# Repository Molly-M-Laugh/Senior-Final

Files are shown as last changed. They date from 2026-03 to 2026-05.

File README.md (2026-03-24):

## Welcome to Our Senior Design Project!

### Hardware

Put some base organization, hardware files in general should be put into the overall hardware folder unless:

- Microcontroller, should go into a designated section of software rather (TBD)
- Finalized circuits, hardware spec docs, and fabric designs (and others TBD) have specific hardware sub-folders

### Software

This folder includes our work on everything in our software stack. We have our code for our ESP32 handling BLE communication, IOS app code, our frontend website, and our backend api.

### Citations
We use a third party library that has been included into our repository because it was the only way to upload our work to the phone that we are developing on without deploying it. The library is called Alamofire, it's used for HTTP communication in Swift. You can find it at Software/BLE-IOS/Alamofire

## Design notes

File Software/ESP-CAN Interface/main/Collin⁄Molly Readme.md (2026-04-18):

# Cell_F103 ESP32

## Architecture

```
STM32 Sensor Node
      │
      │  CAN FD bus (hardware, done)
      │
   ESP32
      ├── can_ctrl.c     (done — do not modify)
      ├── mcp_port.c     (done — do not modify)
      ├── app_main.c     (Cannibalize into already done base)
      │
      └── ble_ctrl.c     ← Collin/Molly
      └── ble_ctrl.h     ← Collin/Molly
      │
      │  BLE 4.2
      │
   Mobile App
```

Data flows in two directions:

- **Telemetry (STM32 → App):** Hardware publishes sensor readings,
  power states, and alerts. `app_main.c` receives these and posts them
  to a queue. `ble_forward_task` drains the queue and calls
  `ble_ctrl_notify()` to push data to the connected mobile app.

- **Commands (App → STM32):** The mobile app writes to a BLE
  characteristic. The BLE write handler calls one of the pre-built
  `can_ctrl_send_cmd_*()` functions

---

## To-Do

### 1. `ble_ctrl_init()`

Called once at startup from `app_main.c`. Set up a GATT server with
the service and characteristics listed in the table below, then start
advertising so the mobile app can connect.

### 2. `ble_ctrl_notify(uint8_t char_id, const uint8_t *data, uint8_t len)`

Called from `ble_forward_task` in `app_main.c` when a telemetry frame
arrives. Send a BLE notification on the appropriate characteristic.
If no device is connected, discard silently (or buffer, your choice).

### 3. BLE write handler (commands from app → hardware)

When the mobile app writes to a command characteristic, call the
appropriate pre-built function from `can_ctrl.h`. See the command
table below for the exact function to call.

---

## GATT Service Layout

Use a custom 128-bit service UUID. Suggested base:
At Colins/Mollys discretion

### Telemetry Characteristics (notify, read)

These are written by the ESP32 and read/subscribed to by the mobile app.

| Characteristic | `char_id` constant | What it contains | Update rate |
|---|---|---|---|
| Sensor Data | `BLE_CHAR_SENSOR_DATA` | Temperatures (×3), current (×3), voltage (×3) | Periodic (~1 Hz) |
| Power State | `BLE_CHAR_POWER_STATE` | Which rails are on, fault flags | On change |
| Fault Alert | `BLE_CHAR_FAULT_ALERT` | Power rail fault condition | Event-driven |
| Temp Alert | `BLE_CHAR_TEMP_ALERT` | Which sensor, which limit, what reading | Event-driven |
| FRAM Log | `BLE_CHAR_FRAM_LOG` | Historical log chunk (48 bytes per chunk) | On request |

> **Note on alerts:** Use BLE **indications** (confirmed delivery) for
> `FAULT_ALERT` and `TEMP_ALERT` rather than unconfirmed notifications.
> These are safety-critical events.

### Command Characteristics (write, write-no-response)

These are written by the mobile app to control the hardware.

| Characteristic | `char_id` constant | Function to call | What it does |
|---|---|---|---|
| Power Control | `BLE_CHAR_CMD_POWER` | `can_ctrl_send_cmd_power(&pkt)` | Enable/disable a power rail |
| Temp Threshold | `BLE_CHAR_CMD_TEMP_THRESH` | `can_ctrl_send_cmd_temp_thresh(&pkt)` | Update a temperature alert limit |
| Temp Request | `BLE_CHAR_CMD_TEMP_REQ` | `can_ctrl_send_cmd_temp_req(&pkt)` | Request an immediate sensor reading |
| Alert Ack | `BLE_CHAR_CMD_ALERT_ACK` | `can_ctrl_send_cmd_alert_ack(&pkt)` | Acknowledge a temperature alert |

---

## Payload Structures

All payload structs are defined in `can_ctrl.h`. You do not need to
parse them on the ESP32 side, just forward the raw bytes to the mobile
app. The mobile app should parse them due to additional base overhead that would be added to the MCUs.

If you do need to inspect a field (e.g. for logging), the structs are:

```c
// Sensor data — arrives on BLE_CHAR_SENSOR_DATA
// Temperatures: divide temp_raw[n] by 16 to get °C as a float
typedef struct __attribute__((packed)) {
    can_frame_header_t hdr;       // 4 bytes — protocol header, ignore
    int16_t  temp_raw[3];         // TMP75B sensors 0/1/2
    int16_t  current_ma[3];       // INA3221 CH1/2/3 in mA
    uint16_t voltage_mv[3];       // INA3221 CH1/2/3 in mV
    uint32_t timestamp_ms;        // milliseconds since boot
} can_payload_sensor_data_t;      // 26 bytes total

// Power state — arrives on BLE_CHAR_POWER_STATE
typedef struct __attribute__((packed)) {
    can_frame_header_t hdr;
    uint8_t  rails_enabled;       // bit0=5V, bit1=3V3, bit2=1V8
    uint8_t  rails_pg;            // bit0=5V power-good, bit1=3V3 power-good
    uint8_t  fault_flags;         // non-zero means a rail has faulted
    uint8_t  reserved;
    uint32_t timestamp_ms;
} can_payload_power_state_t;      // 12 bytes

// Fault alert — arrives on BLE_CHAR_FAULT_ALERT
typedef struct __attribute__((packed)) {
    can_frame_header_t hdr;
    uint8_t  fault_flags;         // which rails faulted (same bit layout as above)
    uint8_t  reserved[3];
    uint32_t timestamp_ms;
} can_payload_fault_alert_t;      // 12 bytes

// Temperature alert — arrives on BLE_CHAR_TEMP_ALERT
typedef struct __attribute__((packed)) {
    can_frame_header_t hdr;
    uint8_t  sensor_idx;          // which sensor (0, 1, or 2)
    uint8_t  alert_type;          // 0 = high limit breached, 1 = low limit
    int16_t  temp_raw;            // current reading (divide by 16 for °C)
    int16_t  threshold_raw;       // the limit that was breached
    uint8_t  reserved[2];
    uint32_t timestamp_ms;
} can_payload_temp_alert_t;       // 16 bytes
```

### Building a command packet

When the app sends a command, you build a packet and call the
appropriate function. Example if the app requests an immediate reading:

```c
#include "can_ctrl.h"

void on_ble_temp_req_write(const uint8_t *data, uint16_t len)
{
    can_payload_cmd_temp_req_t pkt = {0};
    // hdr is filled automatically inside can_ctrl_send_cmd_temp_req()
    pkt.sensor_mask = 0x07;   // request all three sensors (bits 0,1,2)
    can_ctrl_send_cmd_temp_req(&pkt);
}
```

Example if app wants to update a temperature threshold:

```c
void on_ble_temp_thresh_write(const uint8_t *data, uint16_t len)
{
    can_payload_cmd_temp_thresh_t pkt = {0};
    pkt.sensor_idx    = data[0];          // 0, 1, or 2
    pkt.limit_type    = data[1];          // 0 = T_HIGH, 1 = T_LOW
    pkt.threshold_raw = (int16_t)(data[2] << 4); // °C × 16, e.g. 45°C = 720
    can_ctrl_send_cmd_temp_thresh(&pkt);
}
```

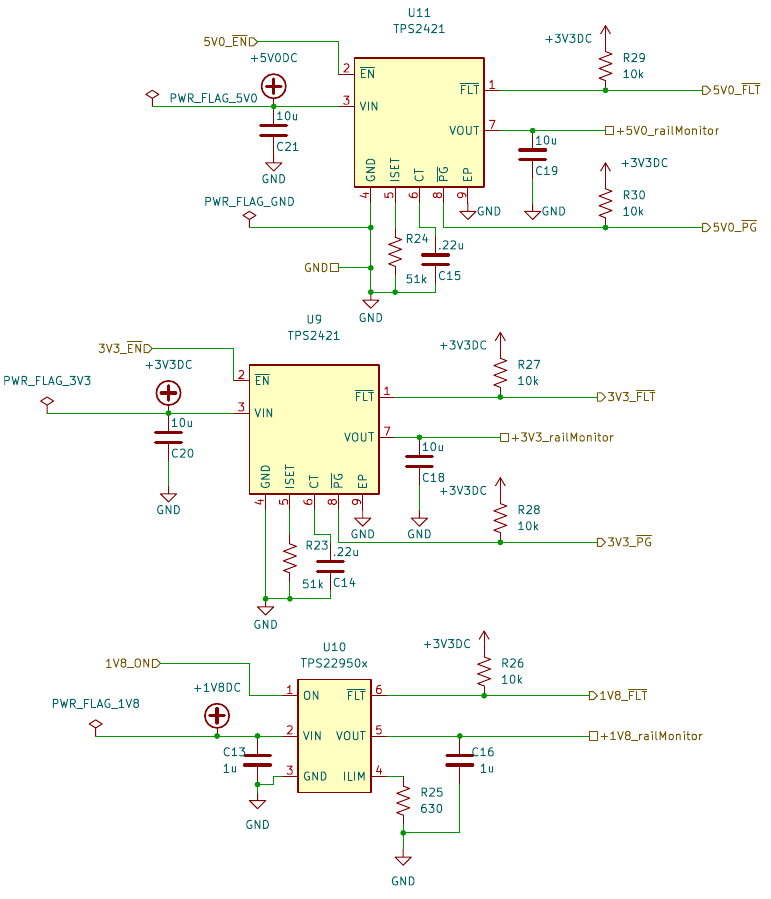
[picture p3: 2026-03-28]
Schematic page 4.png

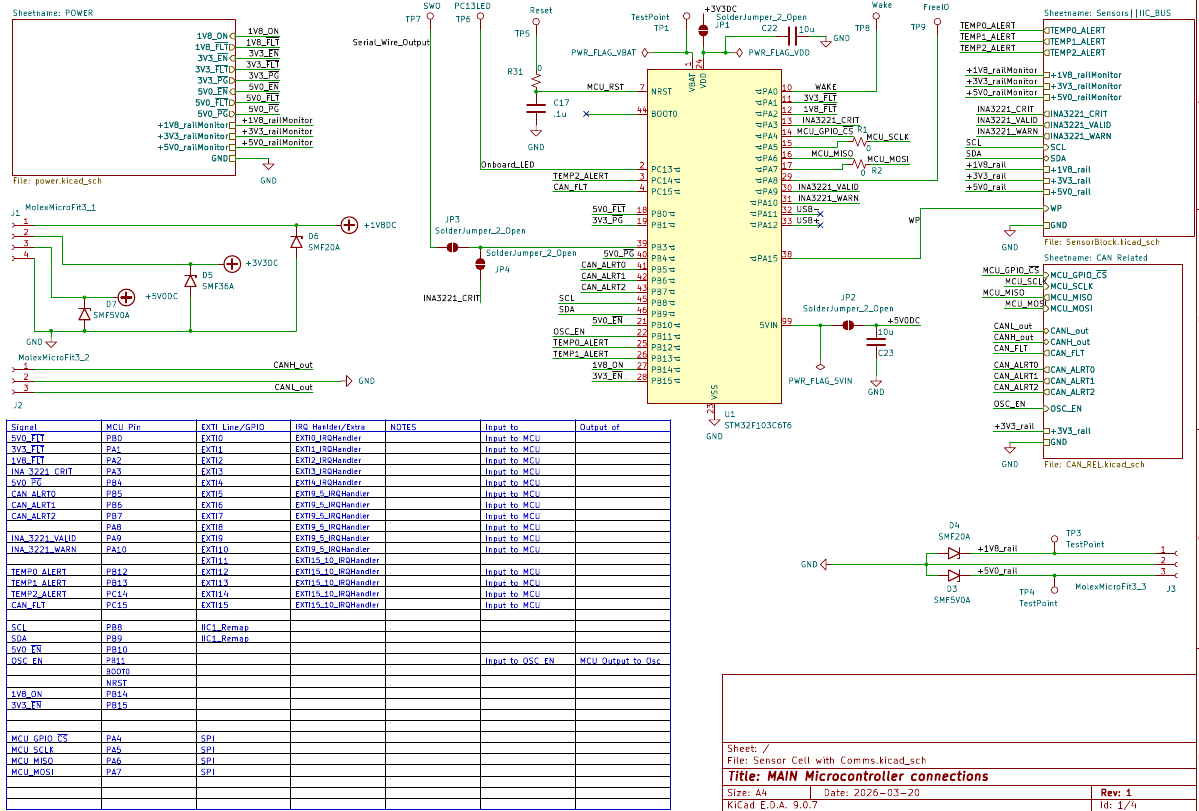
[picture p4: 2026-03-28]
Schematic page 1.png

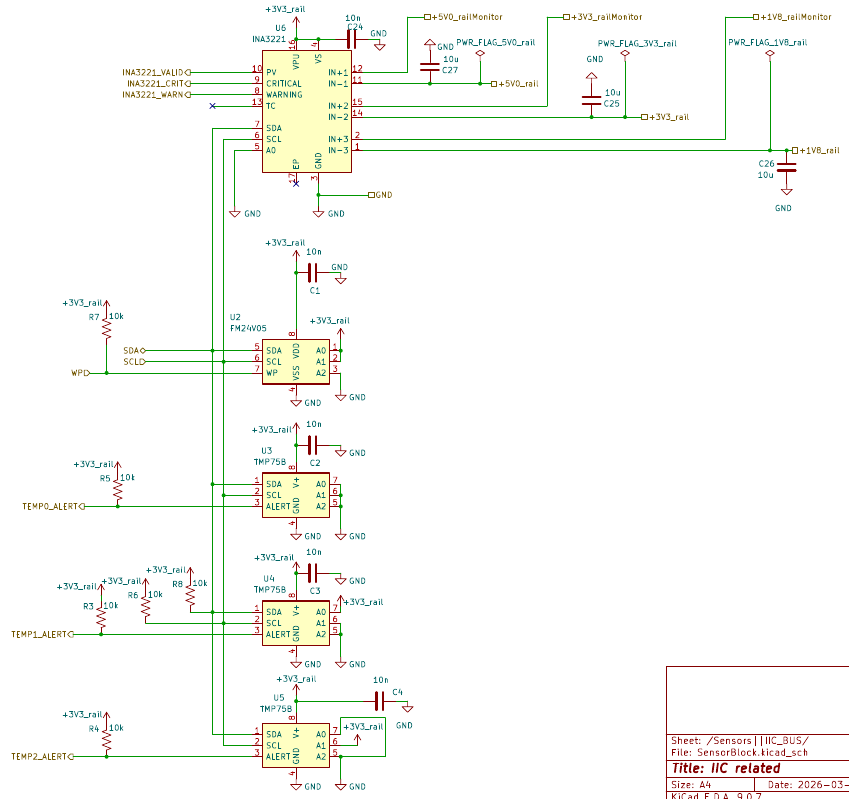
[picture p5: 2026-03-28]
Schematic page 2.png

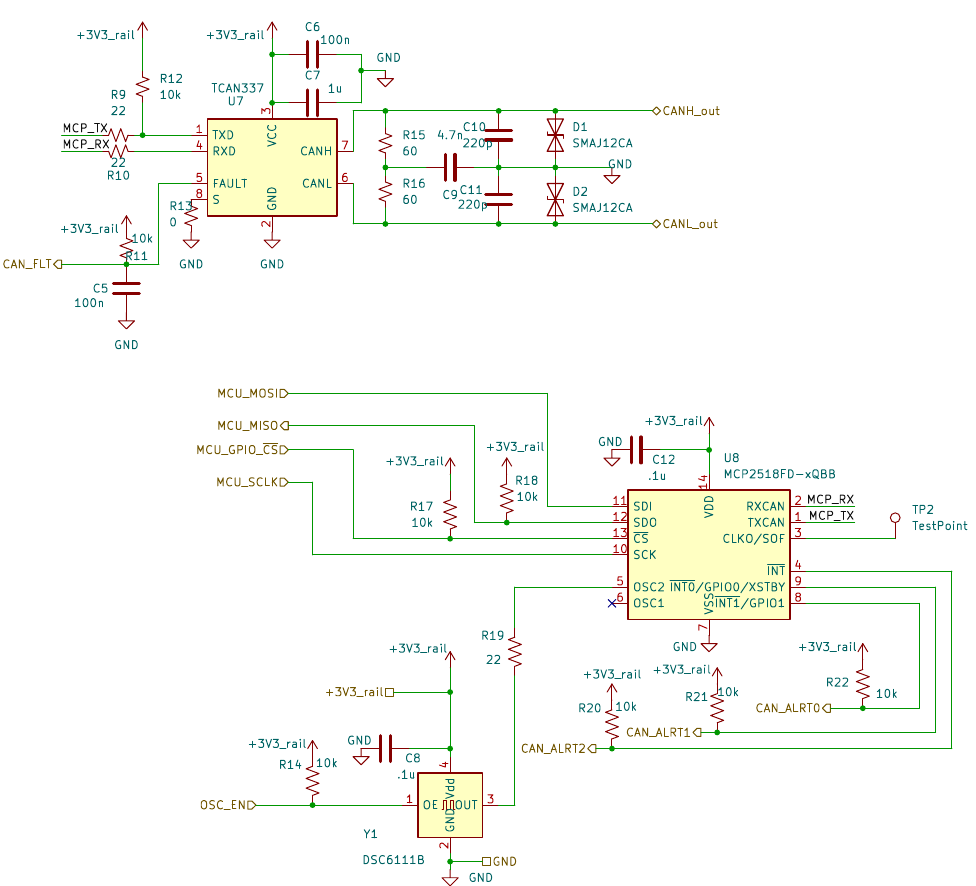
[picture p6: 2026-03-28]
Schematic page 3.png

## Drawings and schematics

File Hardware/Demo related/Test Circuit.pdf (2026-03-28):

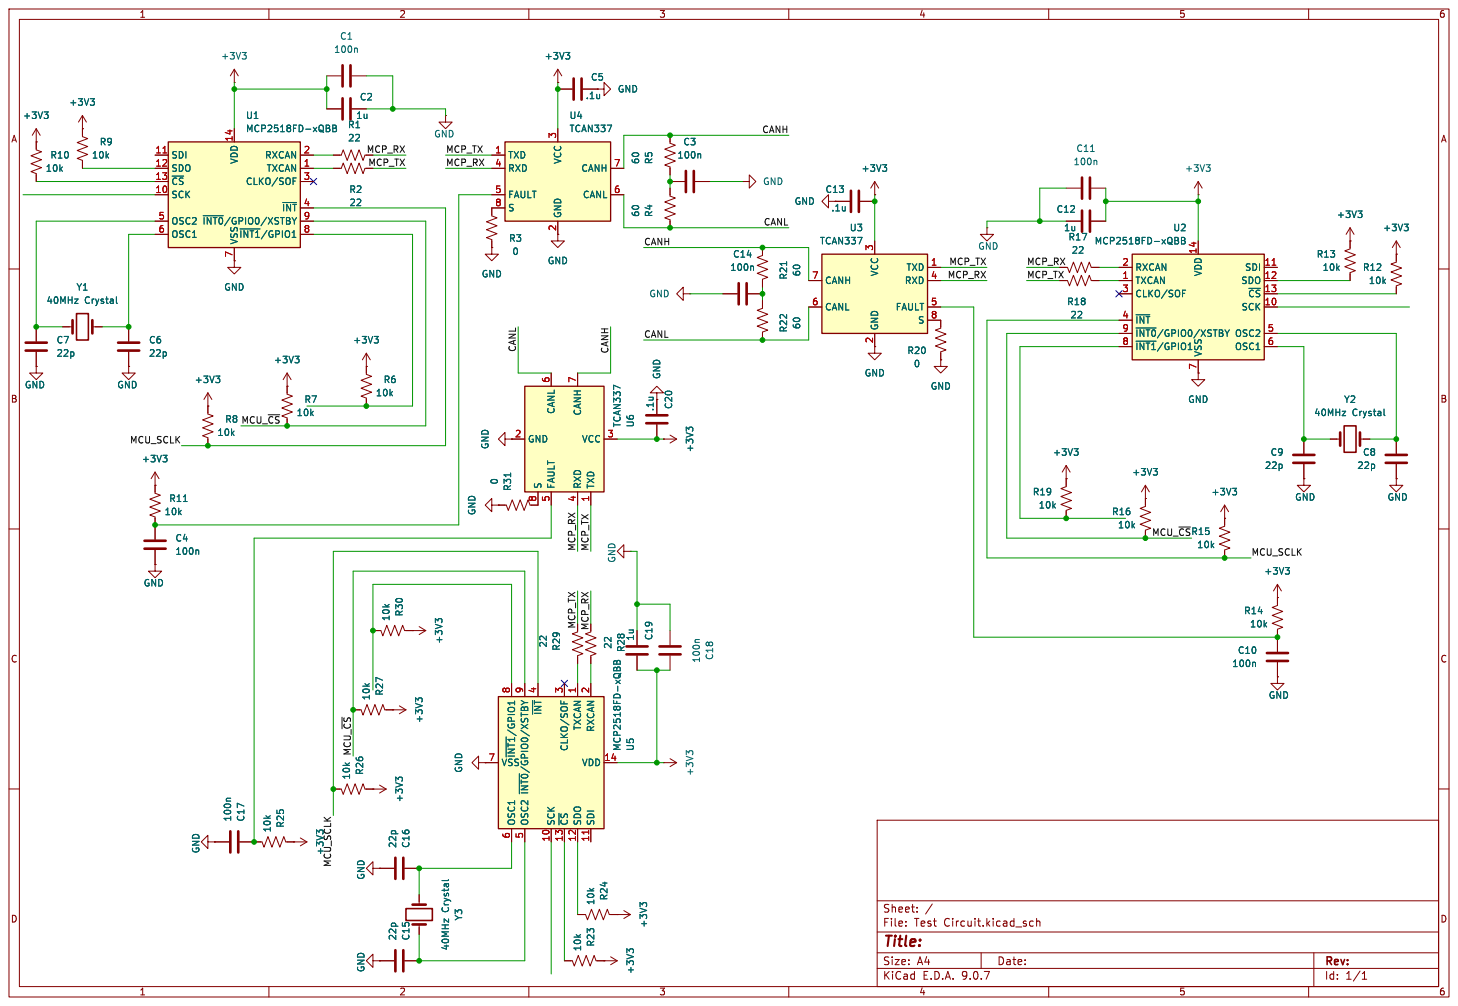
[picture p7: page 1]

7 RXCAN 2 TXCAN 1 CLKO/SOF 3 ~{INT}4 ~{INT0}/GPIO0/XSTBY 9 ~{INT1}/GPIO1 8 U1 MCP2518FD-xQBB GND

7 RXCAN 2 TXCAN 1 CLKO/SOF 3 ~{INT}4 ~{INT0}/GPIO0/XSTBY 9 ~{INT1}/GPIO1 8 GND

2 CANH 7 CANL 6 U3 TCAN337 GND GND

7 RXCAN 2 TXCAN 1 CLKO/SOF 3 ~{INT} 4 ~{INT0}/GPIO0/XSTBY 9 ~{INT1}/GPIO1 8 U2 MCP2518FD-xQBB GND

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

Id: 1/1 Title: File: Test Circuit.kicad_sch Sheet: /

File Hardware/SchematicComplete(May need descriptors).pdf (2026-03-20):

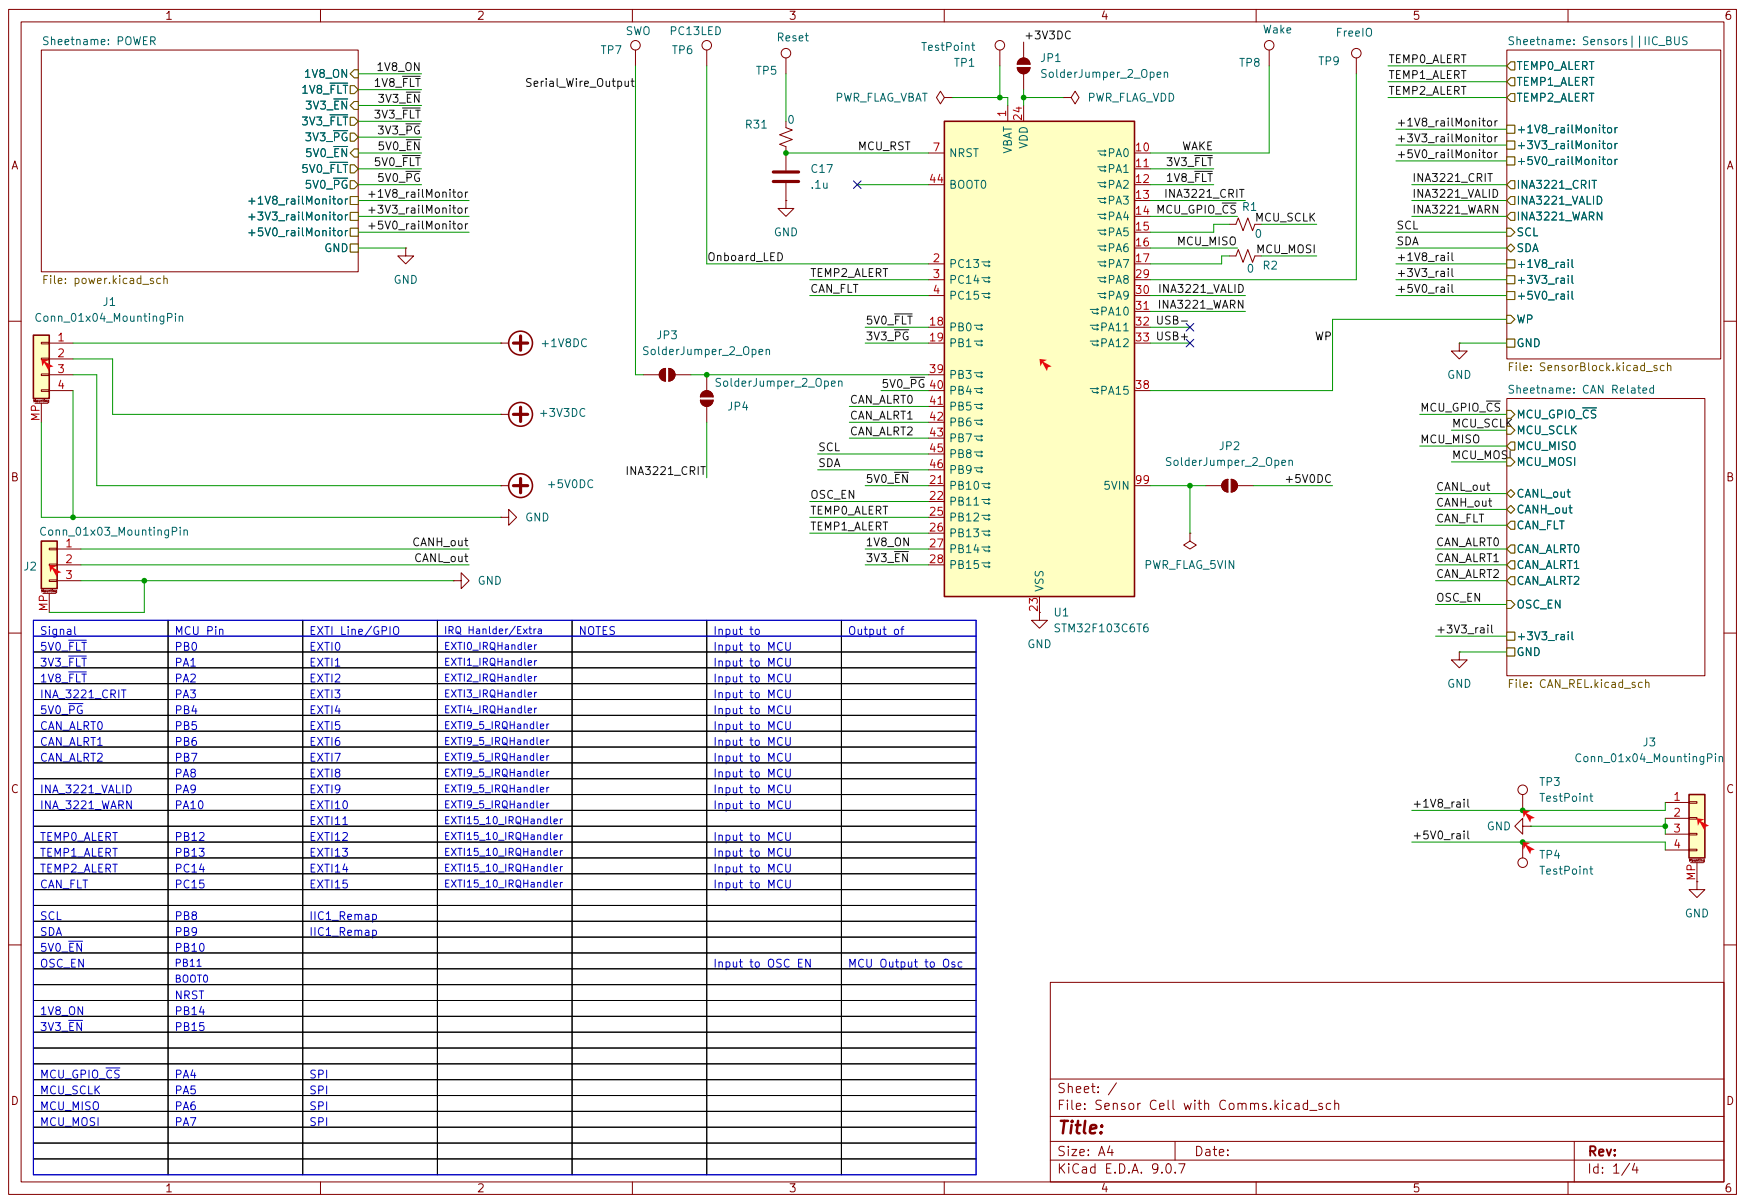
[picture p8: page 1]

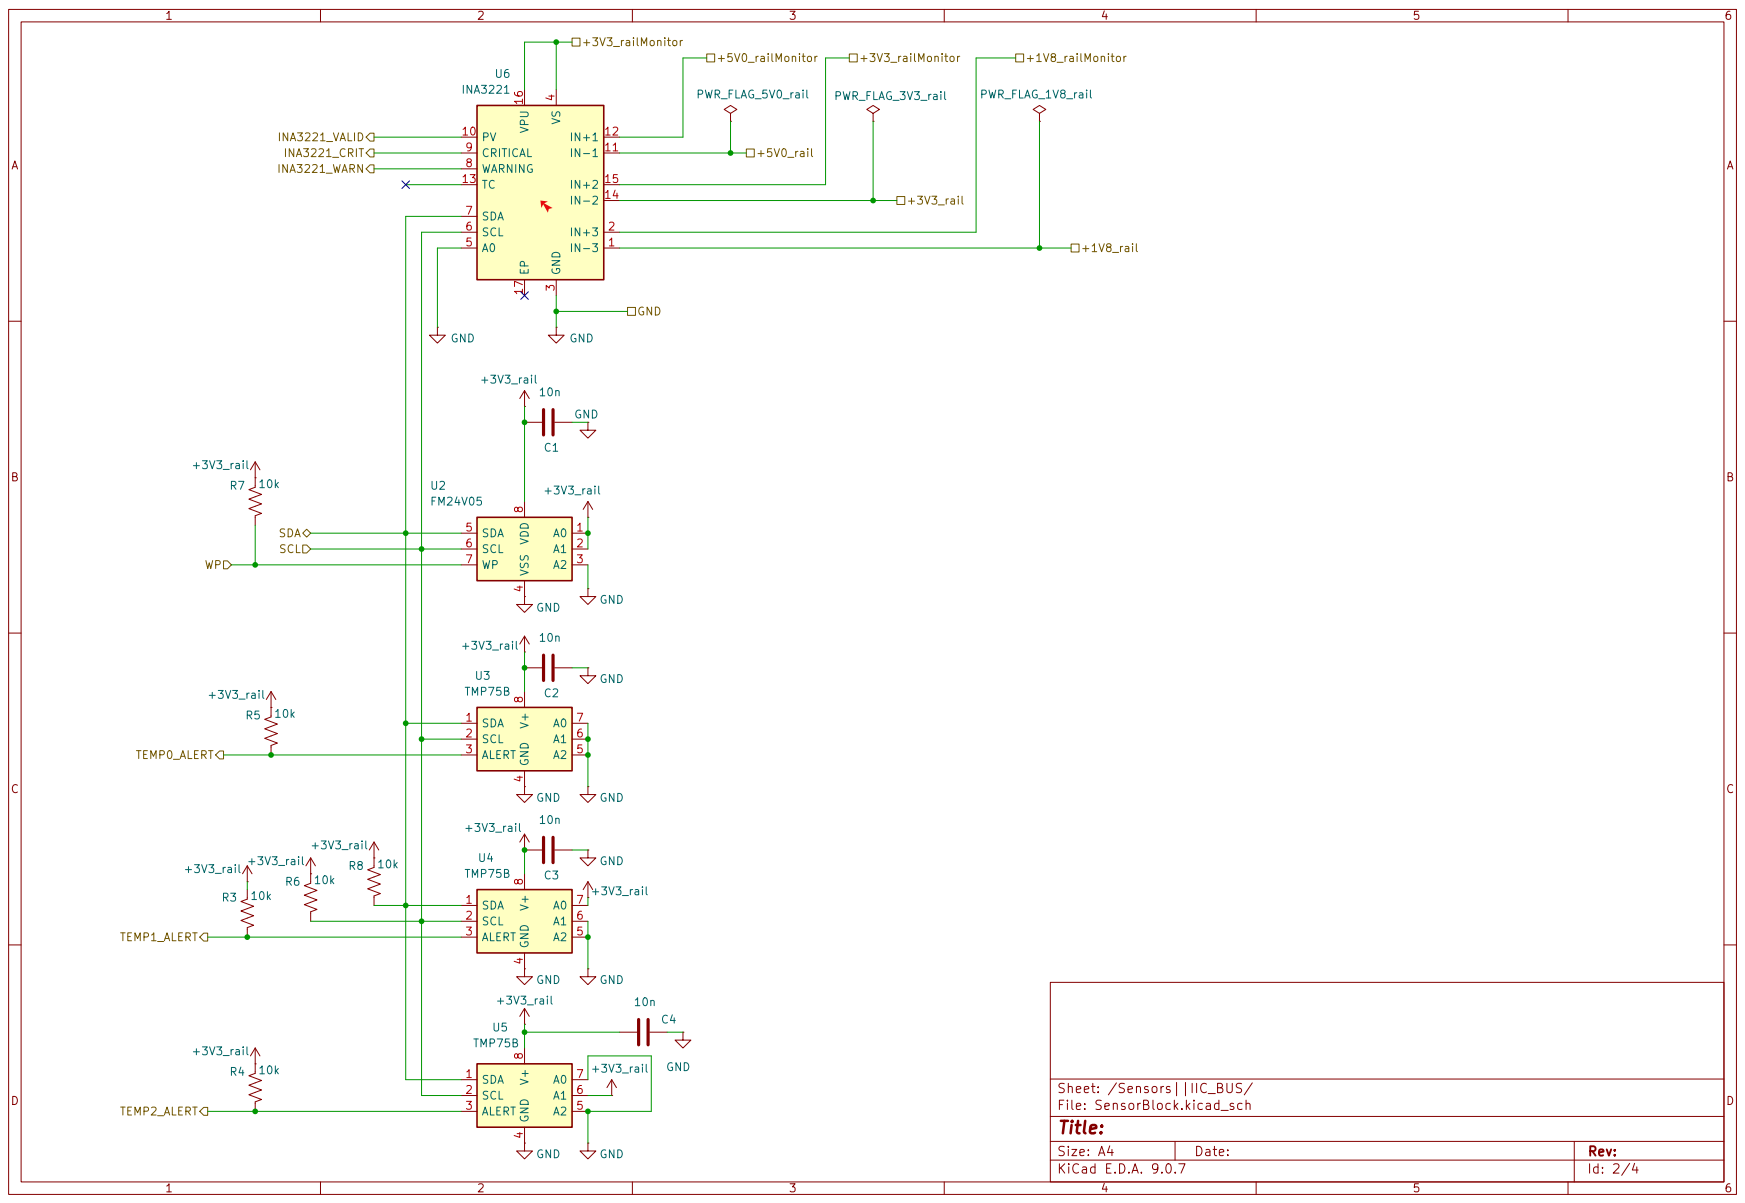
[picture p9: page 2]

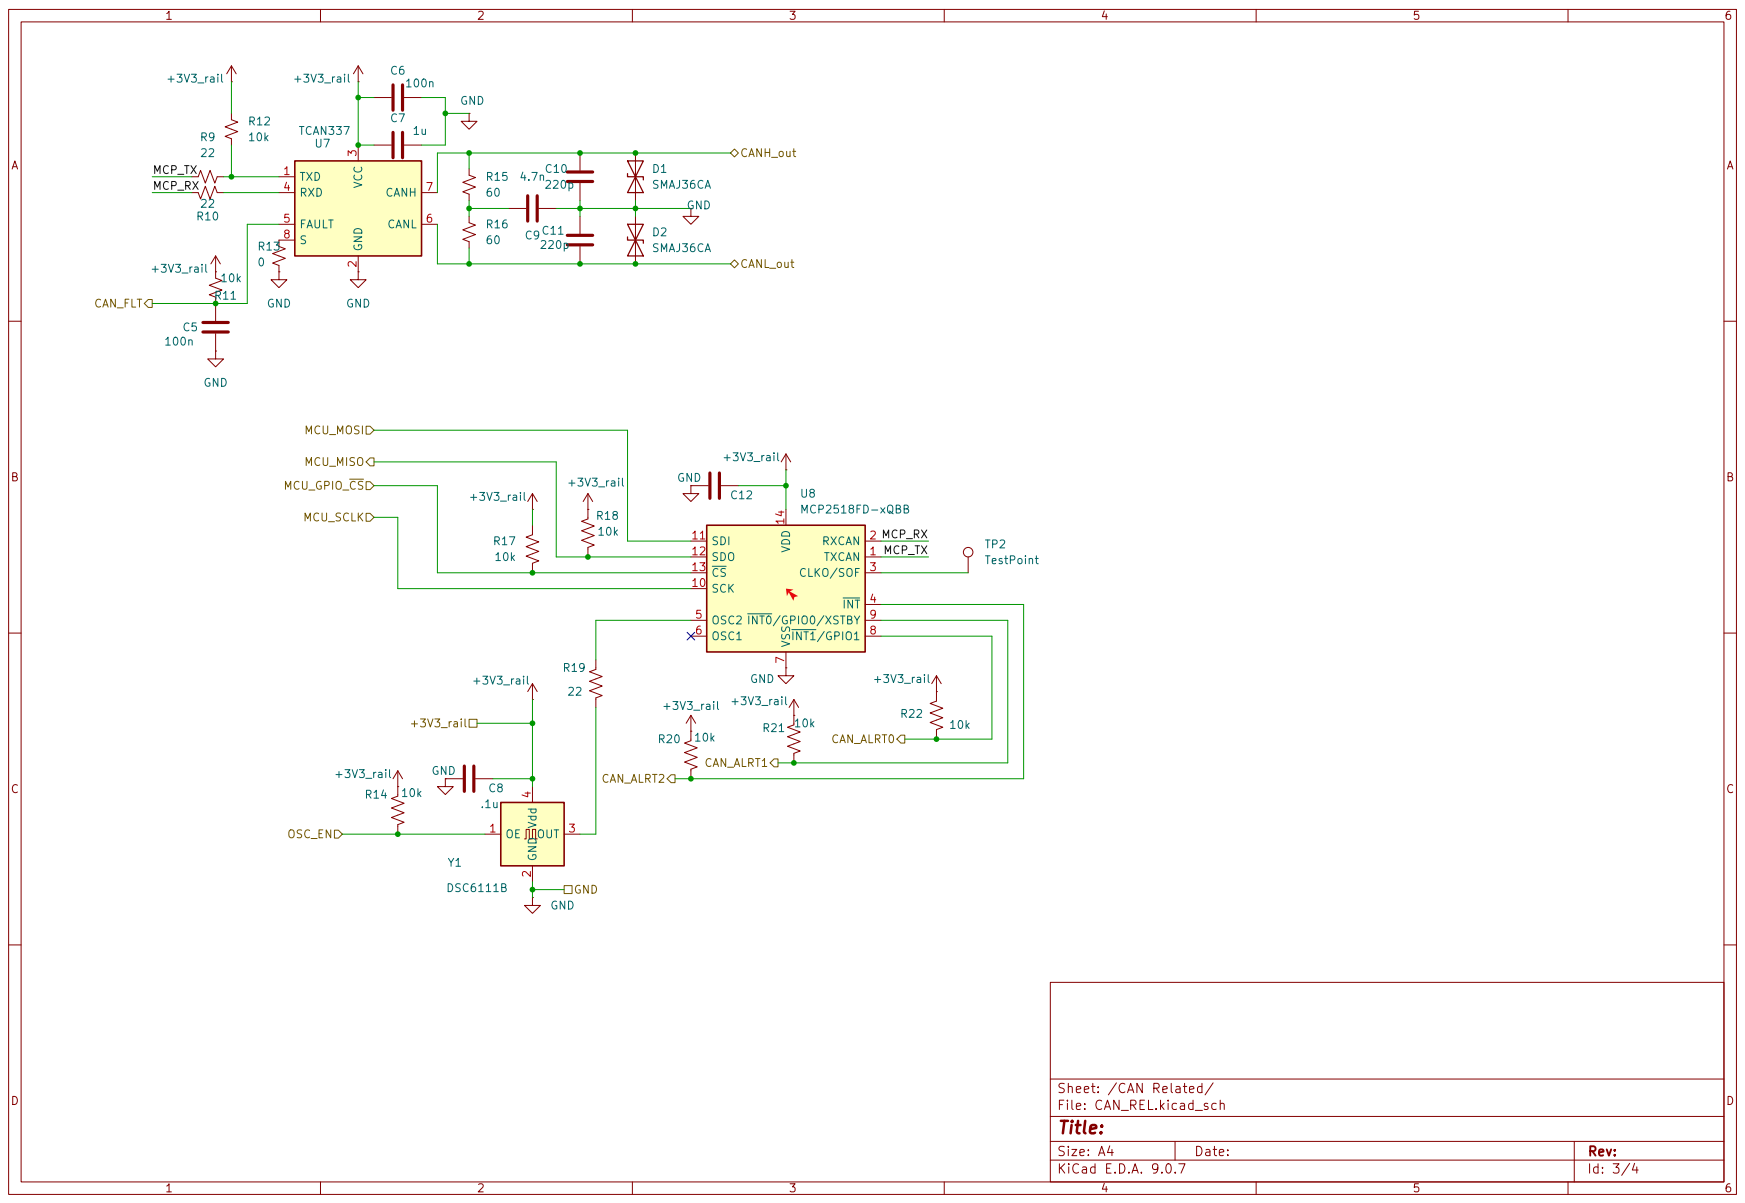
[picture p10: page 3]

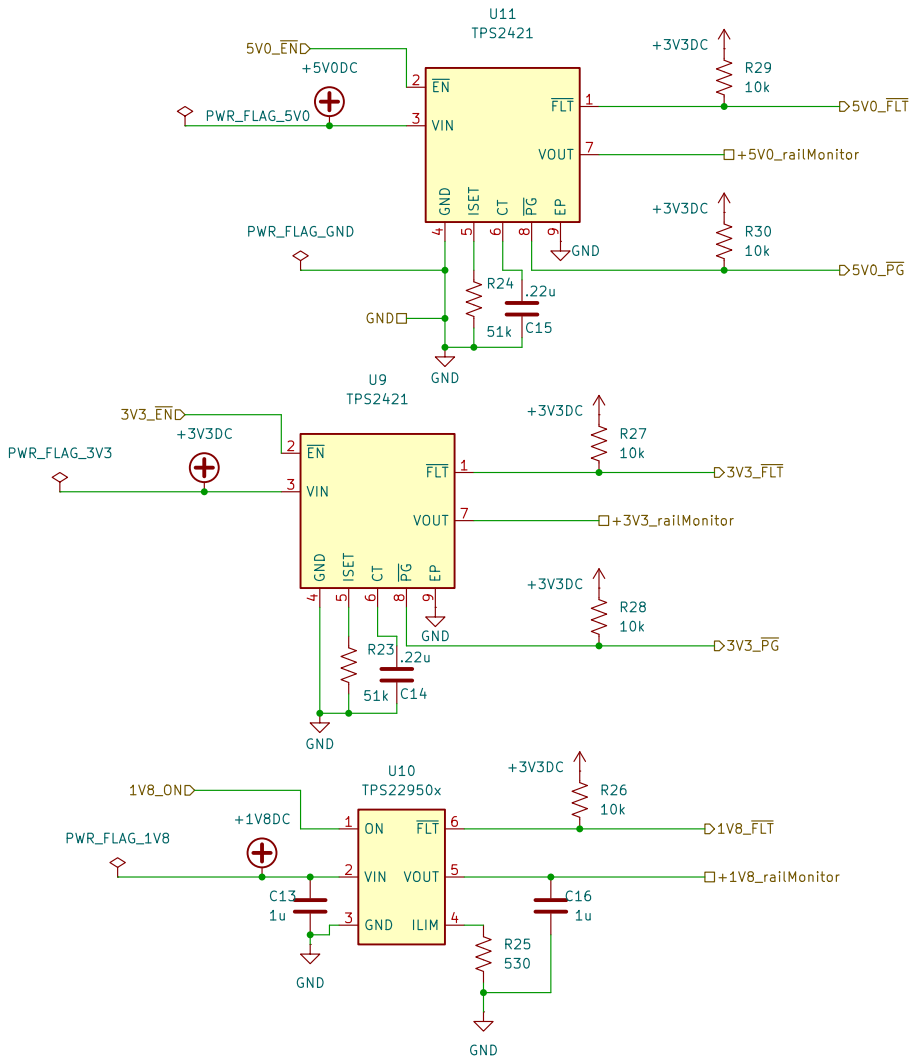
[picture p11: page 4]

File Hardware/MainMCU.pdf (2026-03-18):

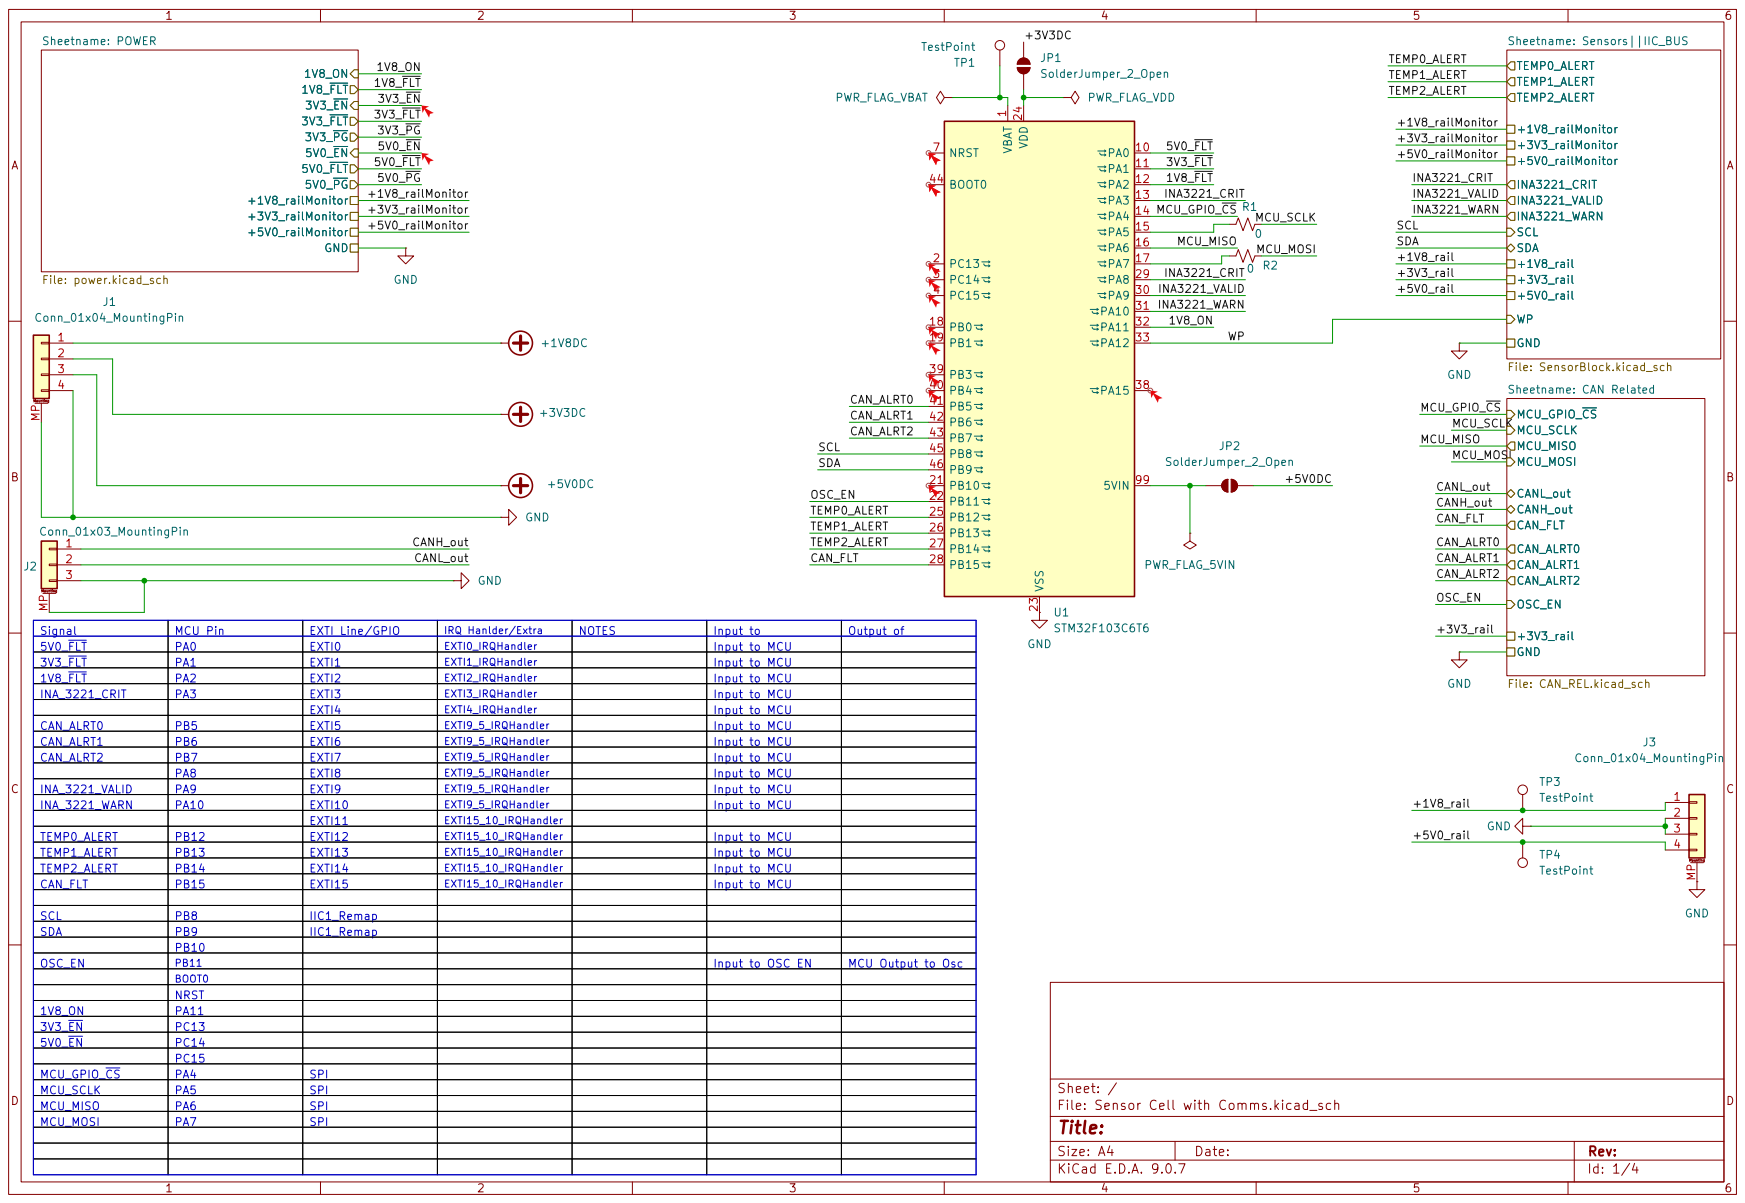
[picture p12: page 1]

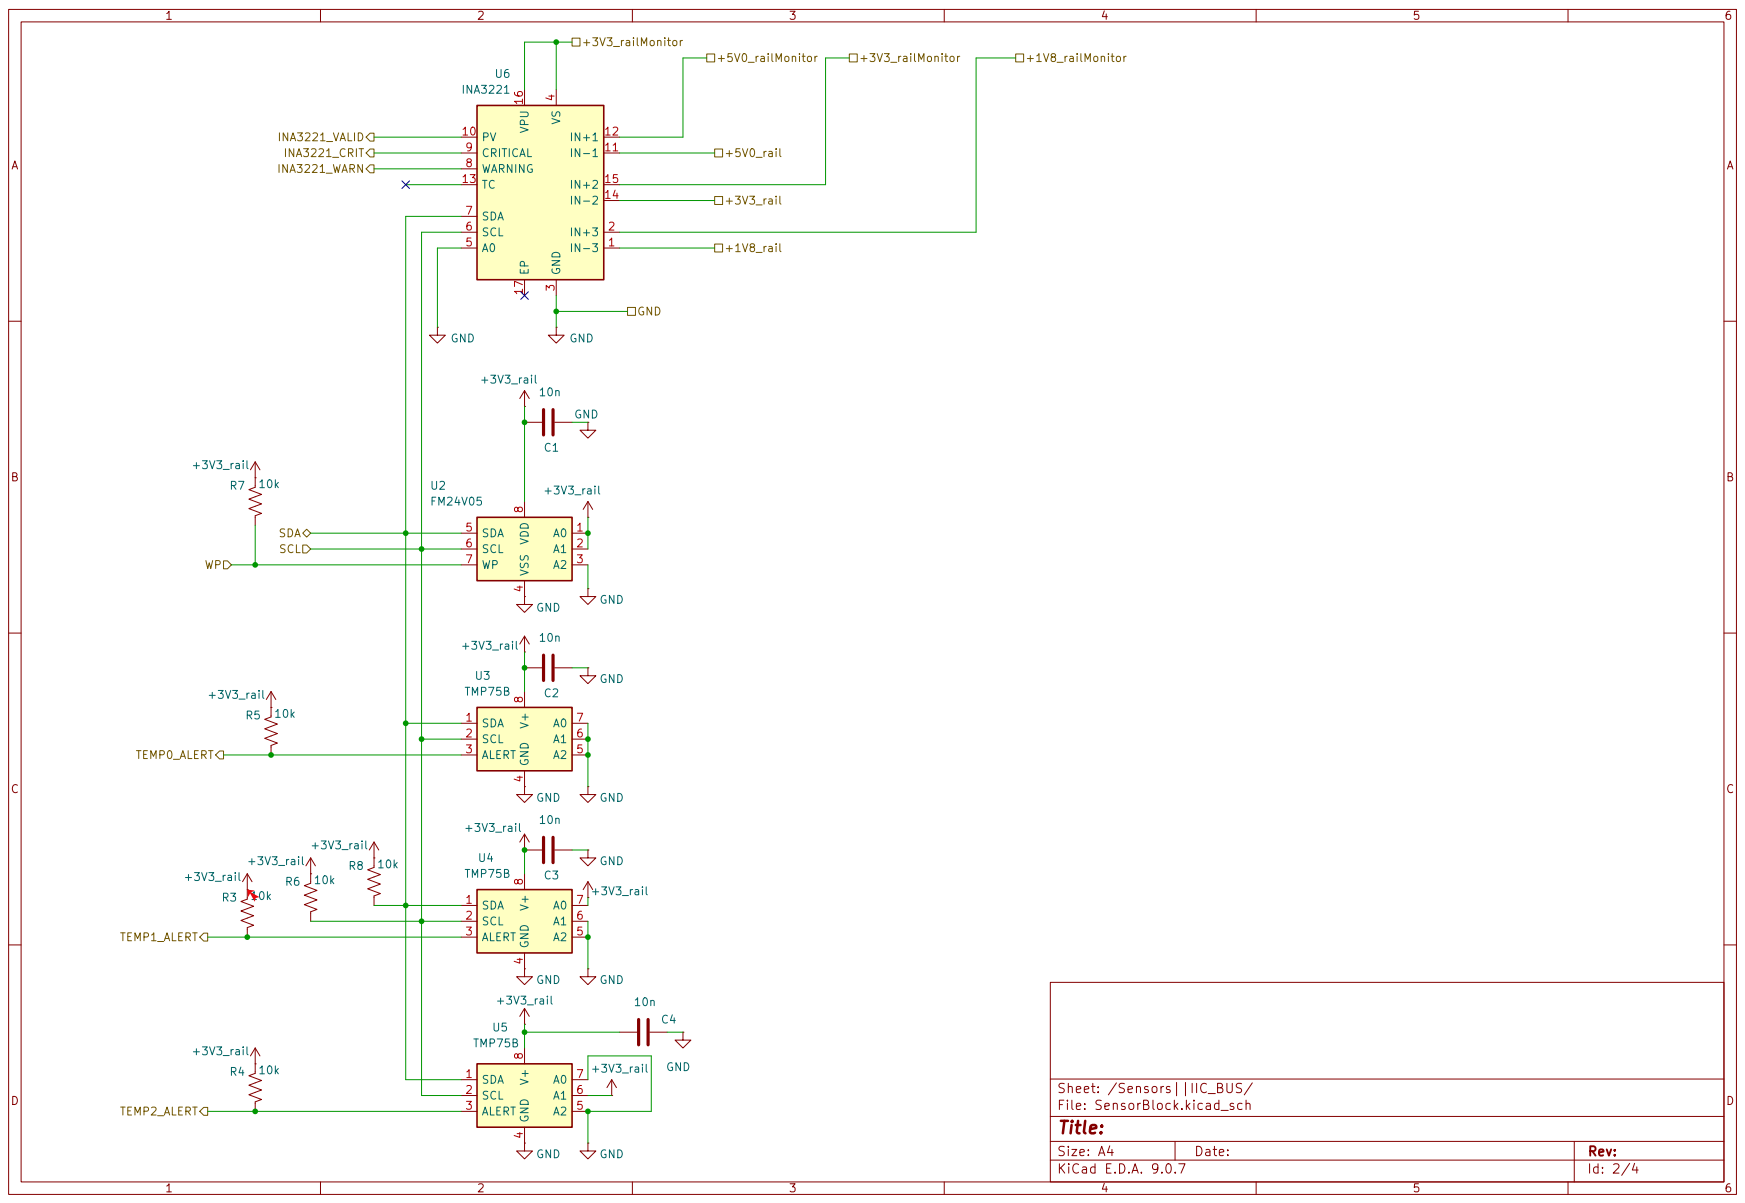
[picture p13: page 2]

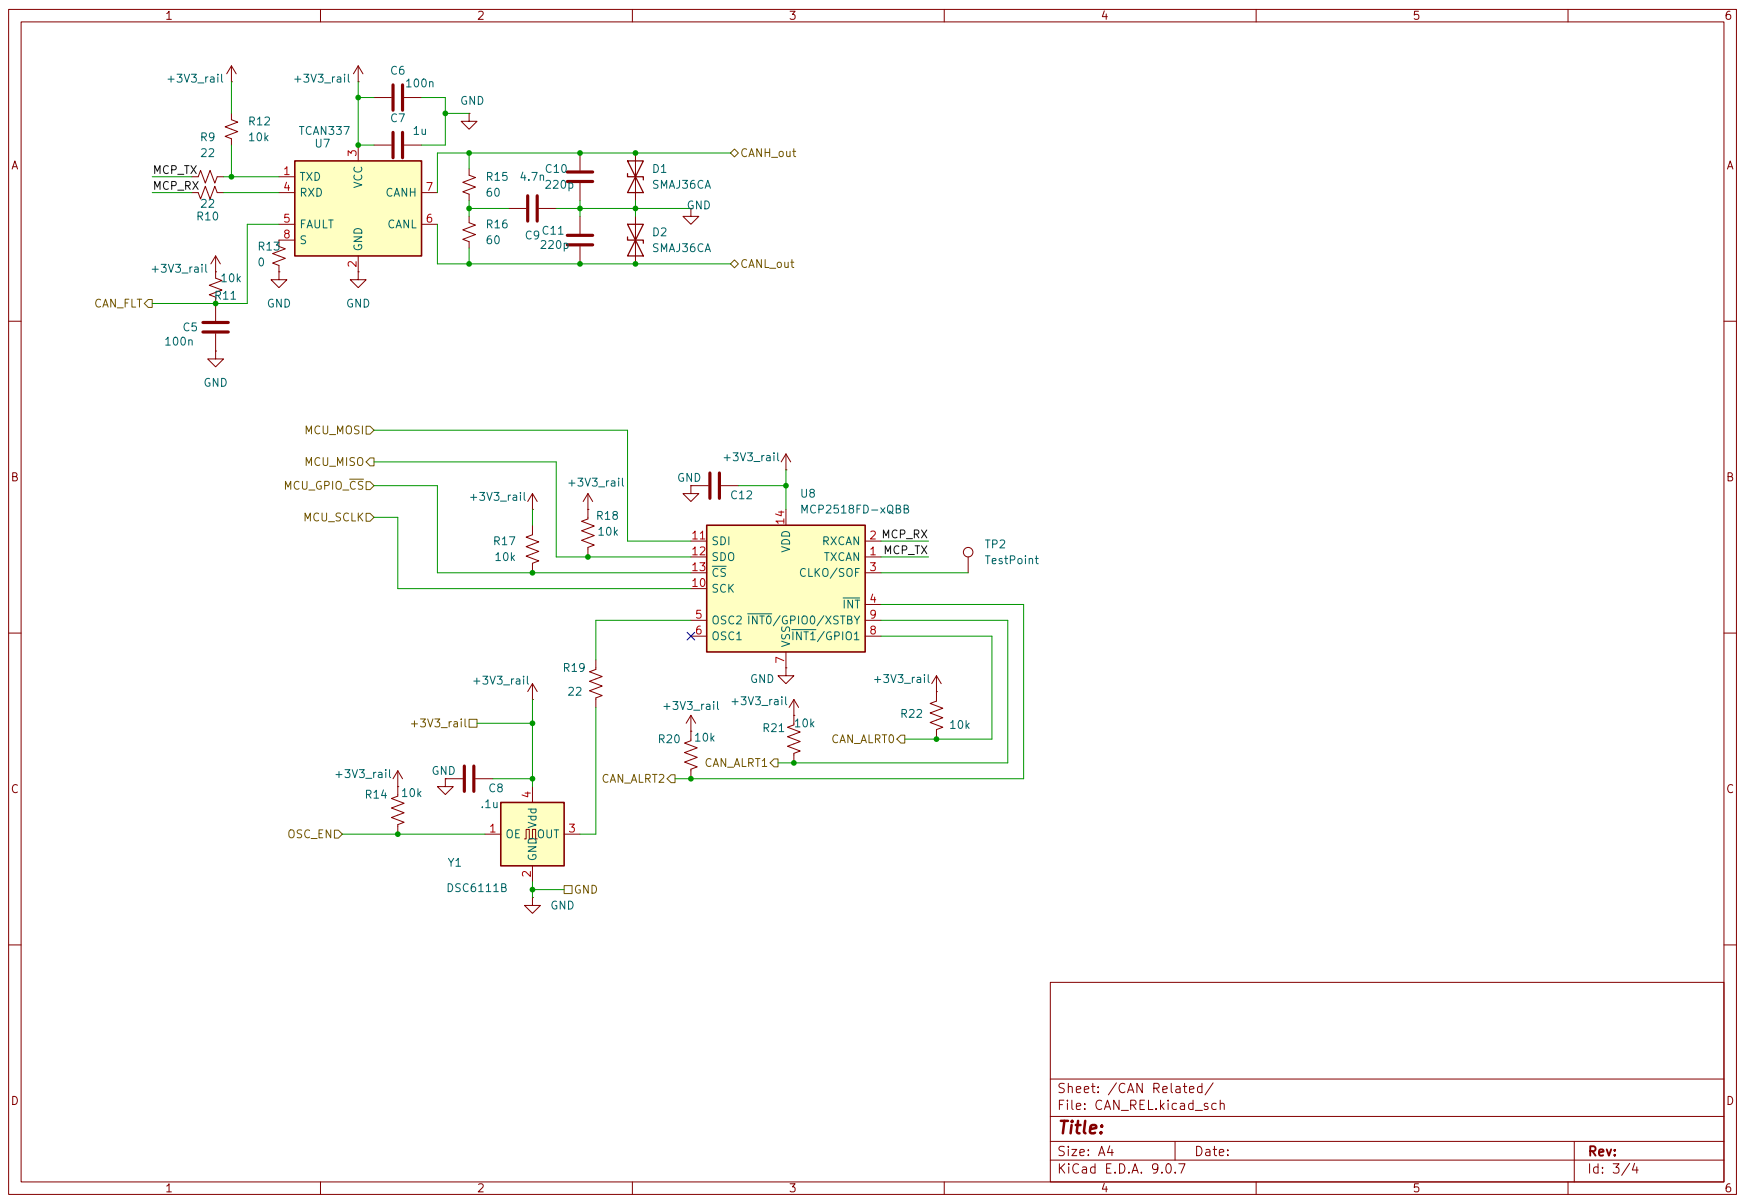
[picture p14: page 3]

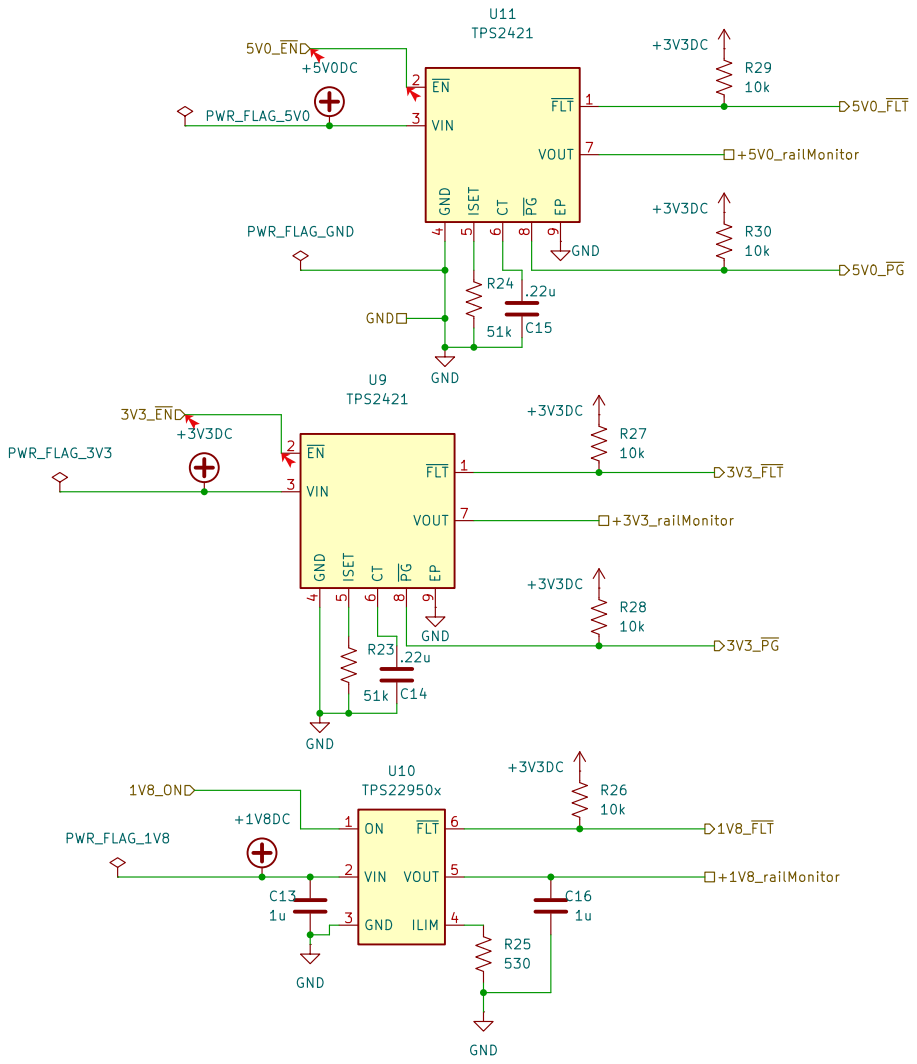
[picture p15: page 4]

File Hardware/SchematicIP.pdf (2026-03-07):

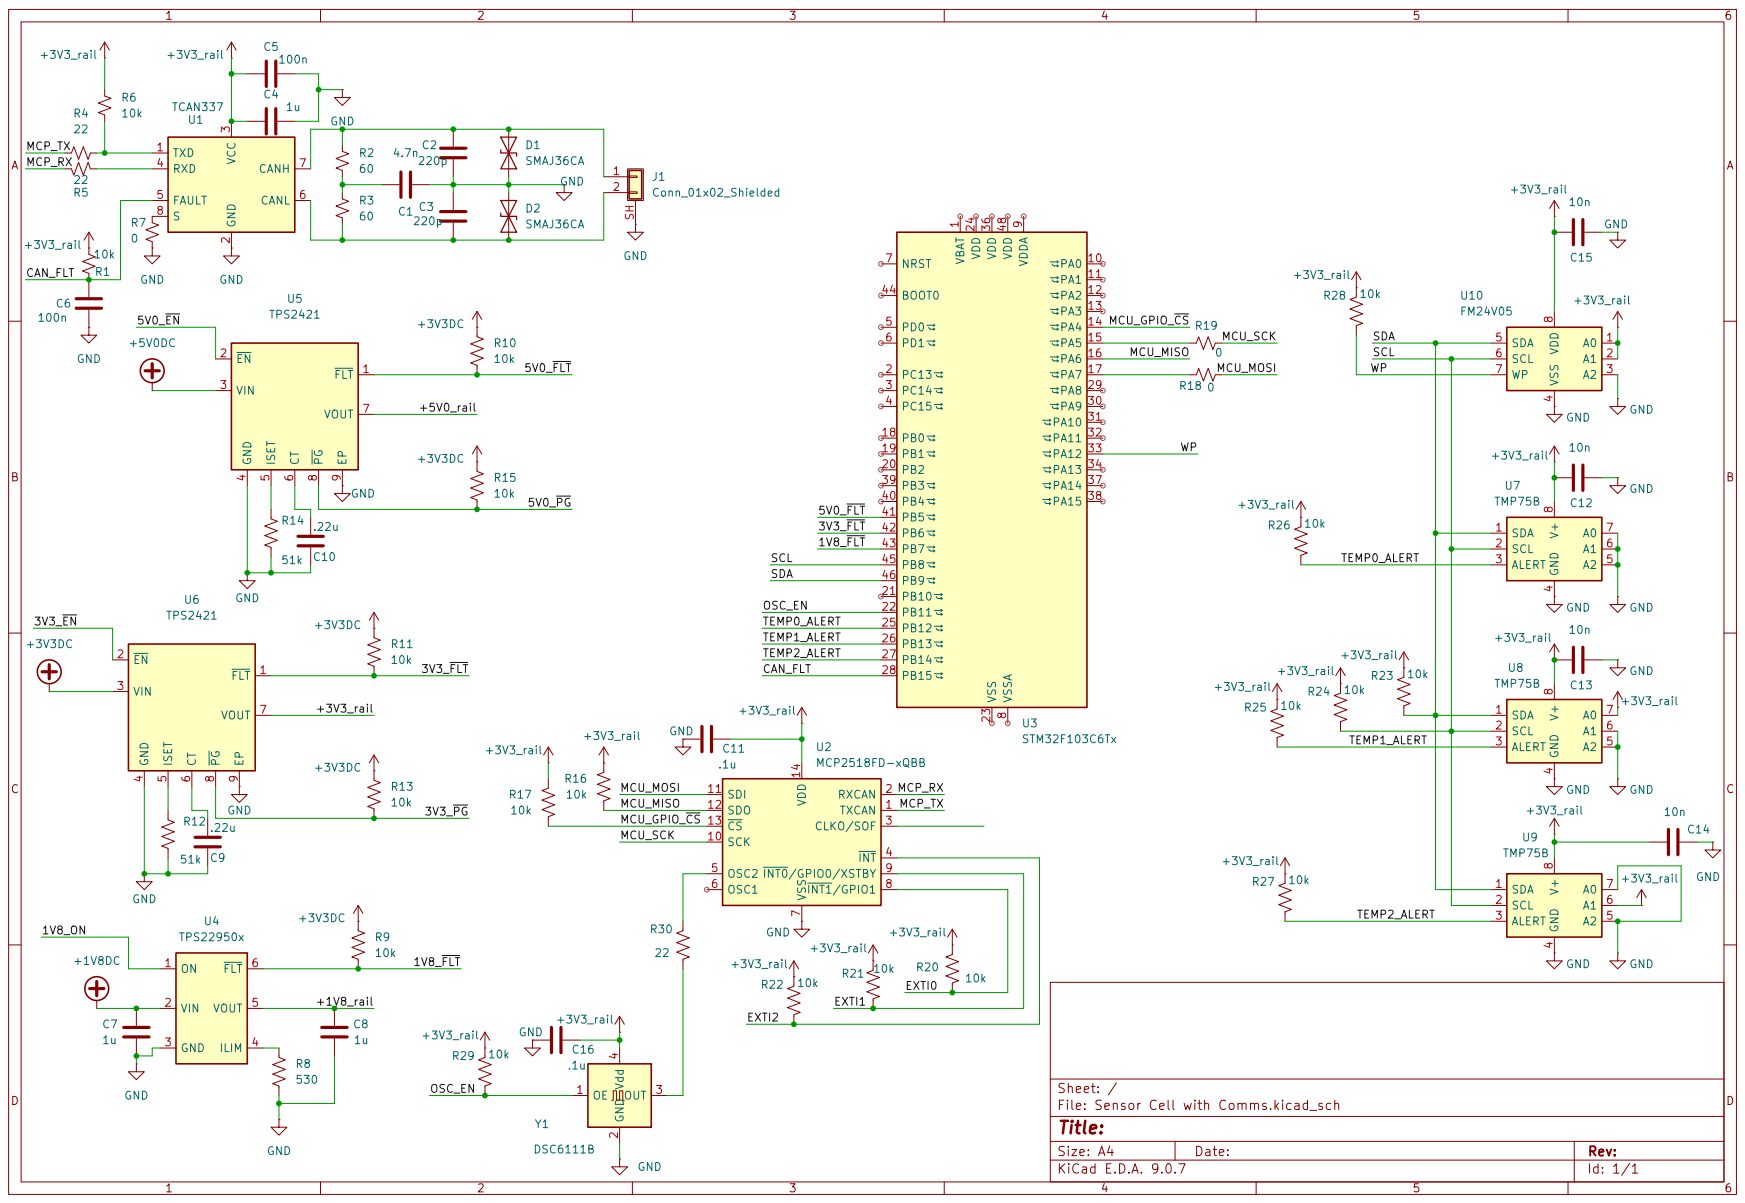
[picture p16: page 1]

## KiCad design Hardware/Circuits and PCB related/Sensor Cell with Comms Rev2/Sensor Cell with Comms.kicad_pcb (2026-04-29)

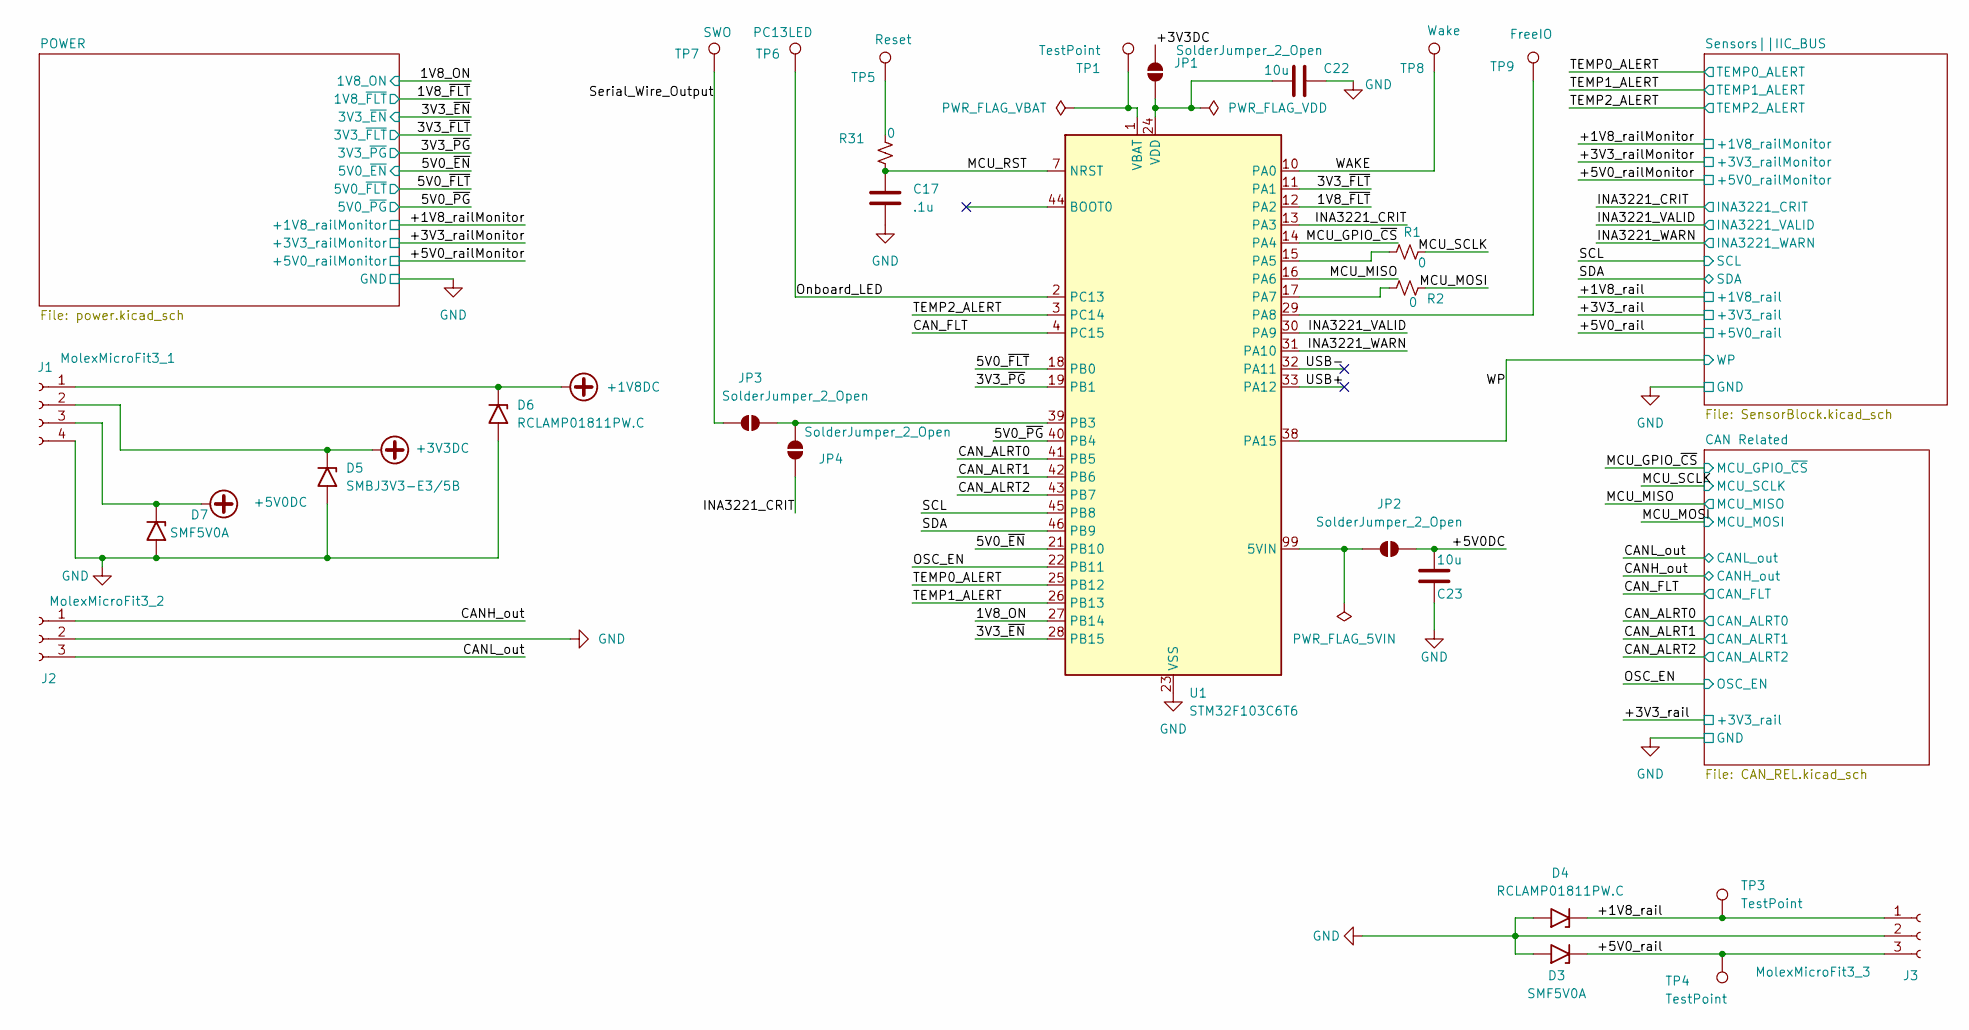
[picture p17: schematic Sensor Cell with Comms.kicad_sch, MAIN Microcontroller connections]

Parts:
C17: .1u; C_0805_2012Metric_Pad1.18x1.45mm_HandSolder
C22, C23: 10u; C_0603_1608Metric_Pad1.08x0.95mm_HandSolder
D3, D7: SMF5V0A; D_SMF
D4, D6: RCLAMP01811PW.C; D_SMF
D5: SMBJ3V3-E3/5B; D_SMF
J1: MolexMicroFit3_1; Molex_Micro-Fit_3.0_43650-0400_1x04_P3.00mm_Horizontal
J2: MolexMicroFit3_2; CONN_SD-43650-001_03_MOL
J3: MolexMicroFit3_3; CONN_SD-43650-001_03_MOL
JP1, JP2, JP3, JP4: SolderJumper_2_Open; SolderJumper-2_P1.3mm_Open_TrianglePad1.0x1.5mm
R1, R2, R31: 0; R_0603_1608Metric_Pad0.98x0.95mm_HandSolder
TP1, TP3, TP4: TestPoint; PinHeader_1x01_P1.00mm_Vertical
TP5: Reset; PinHeader_1x01_P1.00mm_Vertical
TP6: PC13LED; PinHeader_1x01_P1.00mm_Vertical
TP7: SWO; PinHeader_1x01_P1.00mm_Vertical
TP8: Wake; PinHeader_1x01_P1.00mm_Vertical
TP9: FreeIO; PinHeader_1x01_P1.00mm_Vertical
U1: STM32F103C6T6; PinHeader_1x20_P1.00mm_Verticalx2

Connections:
+1V8DC: D6.1 (A1), J1.1; also elsewhere on the board
+3V3DC: D5.1 (A1), J1.2, JP1.2 (B); also elsewhere on the board
+5V0DC: C23.2, D7.1 (A1), J1.3, JP2.2 (B); also elsewhere on the board
/1V8_ON: U1.27 (PB14); also elsewhere on the board
/1V8_~FLT: U1.12 (PA2); also elsewhere on the board
/3V3_~EN: U1.28 (PB15); also elsewhere on the board
/3V3_~FLT: U1.11 (PA1); also elsewhere on the board
/3V3_~PG: U1.19 (PB1); also elsewhere on the board
/5V0_~EN: U1.21 (PB10); also elsewhere on the board
/5V0_~FLT: U1.18 (PB0); also elsewhere on the board
/5V0_~PG: U1.40 (PB4); also elsewhere on the board
/+1V8_rail: D4.1 (A1), J3.1, TP3.1; also elsewhere on the board
/+5V0_rail: D3.1 (A1), J3.3, TP4.1; also elsewhere on the board
/CANH_out: J2.1; also elsewhere on the board
/CANL_out: J2.3; also elsewhere on the board
/CAN_ALRT0: U1.41 (PB5); also elsewhere on the board
/CAN_ALRT1: U1.42 (PB6); also elsewhere on the board
/CAN_ALRT2: U1.43 (PB7); also elsewhere on the board
/CAN_FLT: U1.4 (PC15); also elsewhere on the board
/INA3221_CRIT: JP4.2 (B), U1.13 (PA3); also elsewhere on the board
/INA3221_VALID: U1.30 (PA9); also elsewhere on the board
/INA3221_WARN: U1.31 (PA10); also elsewhere on the board
/MCU_GPIO_~CS: U1.14 (PA4); also elsewhere on the board
/MCU_MISO: U1.16 (PA6); also elsewhere on the board
/MCU_MOSI: R2.1; also elsewhere on the board
/MCU_RST: C17.1, R31.2, U1.7 (NRST)
/MCU_SCLK: R1.1; also elsewhere on the board
/OSC_EN: U1.22 (PB11); also elsewhere on the board
/Onboard_LED: TP6.1, U1.2 (PC13)
/SCL: U1.45 (PB8); also elsewhere on the board
/SDA: U1.46 (PB9); also elsewhere on the board
/Serial_Wire_Output: JP3.1 (A), TP7.1
/TEMP0_ALERT: U1.25 (PB12); also elsewhere on the board
/TEMP1_ALERT: U1.26 (PB13); also elsewhere on the board
/TEMP2_ALERT: U1.3 (PC14); also elsewhere on the board
/USB+: U1.33 (PA12)
/USB-: U1.32 (PA11)
/WAKE: TP8.1, U1.10 (PA0)
/WP: U1.38 (PA15); also elsewhere on the board
unnamed: JP2.1 (A), U1.99 (5VIN)
unnamed: JP3.2 (B), JP4.1 (A), U1.39 (PB3)
unnamed: R31.1, TP5.1
unnamed: R1.2, U1.15 (PA5)
unnamed: R2.2, U1.17 (PA7)
unnamed: TP9.1, U1.29 (PA8)
unnamed: TP1.1, U1.1 (VBAT)

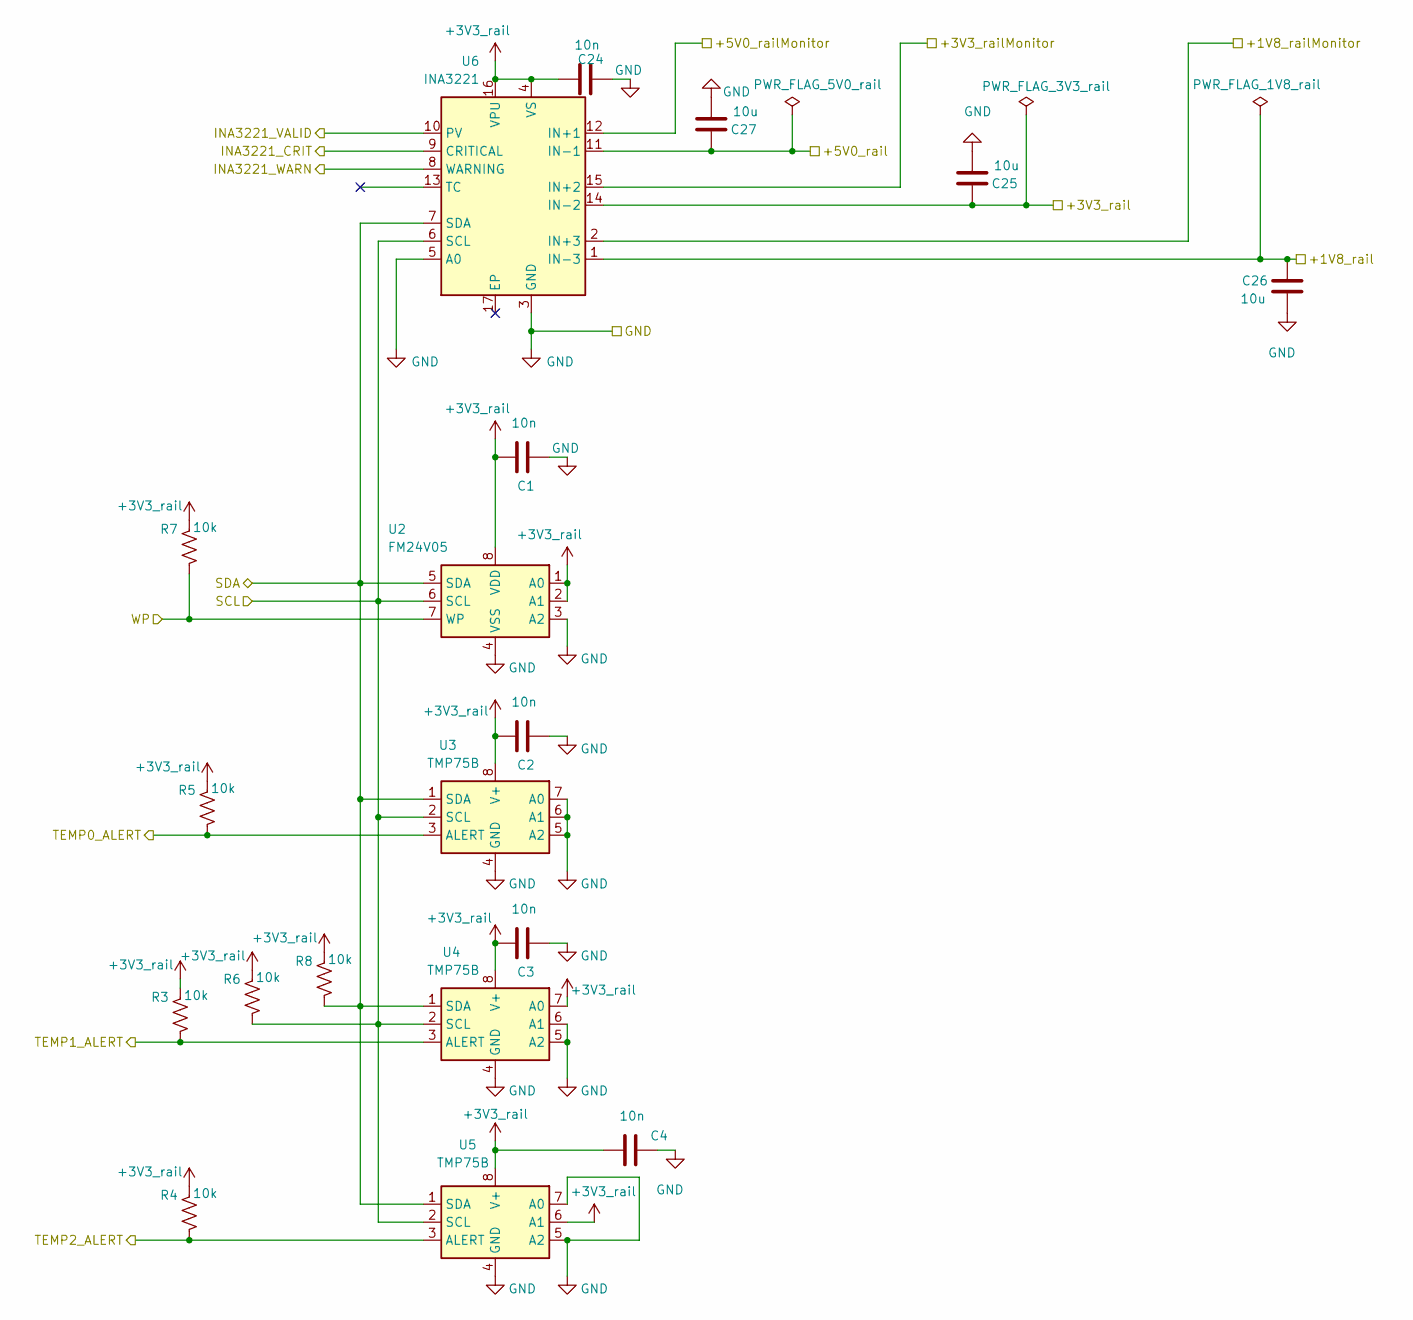
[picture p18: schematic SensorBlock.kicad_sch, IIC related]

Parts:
C1, C2, C3, C4, C24: 10n; C_0603_1608Metric_Pad1.08x0.95mm_HandSolder
C25, C26, C27: 10u; C_0603_1608Metric_Pad1.08x0.95mm_HandSolder
R3, R4, R5, R6, R7, R8: 10k; R_0603_1608Metric_Pad0.98x0.95mm_HandSolder
U2: FM24V05; SOIC-8_3.9x4.9mm_P1.27mm
U3, U4, U5: TMP75B; SO-8_3.9x4.9mm_P1.27mm
U6: INA3221; PinHeader_1x08_P1.00mm_Vertical_addedMonitorLines

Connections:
+3V3_rail: C1.2, C2.2, C3.2, C4.2, C24.2, C25.2, R3.2, R4.2, R5.2, R6.2, R7.2, R8.2, U2.1 (A0), U2.2 (A1), U2.8 (VDD), U3.8 (V+), U4.7 (A0), U4.8 (V+), U5.6 (A1), U5.8 (V+), U6.4 (VS), U6.14 (IN-2), U6.16 (VPU); also elsewhere on the board
/+1V8_rail: C26.2, U6.1 (IN-3); also elsewhere on the board
/+1V8_railMonitor: U6.2 (IN+3); also elsewhere on the board
/+3V3_railMonitor: U6.15 (IN+2); also elsewhere on the board
/+5V0_rail: C27.2, U6.11 (IN-1); also elsewhere on the board
/+5V0_railMonitor: U6.12 (IN+1); also elsewhere on the board
/INA3221_CRIT: U6.9 (CRITICAL); also elsewhere on the board
/INA3221_VALID: U6.10 (PV); also elsewhere on the board
/INA3221_WARN: U6.8 (WARNING); also elsewhere on the board
/SCL: R6.1, U2.6 (SCL), U3.2 (SCL), U4.2 (SCL), U5.2 (SCL), U6.6 (SCL); also elsewhere on the board
/SDA: R8.1, U2.5 (SDA), U3.1 (SDA), U4.1 (SDA), U5.1 (SDA), U6.7 (SDA); also elsewhere on the board
/TEMP0_ALERT: R5.1, U3.3 (ALERT); also elsewhere on the board
/TEMP1_ALERT: R3.1, U4.3 (ALERT); also elsewhere on the board
/TEMP2_ALERT: R4.1, U5.3 (ALERT); also elsewhere on the board
/WP: R7.1, U2.7 (WP); also elsewhere on the board

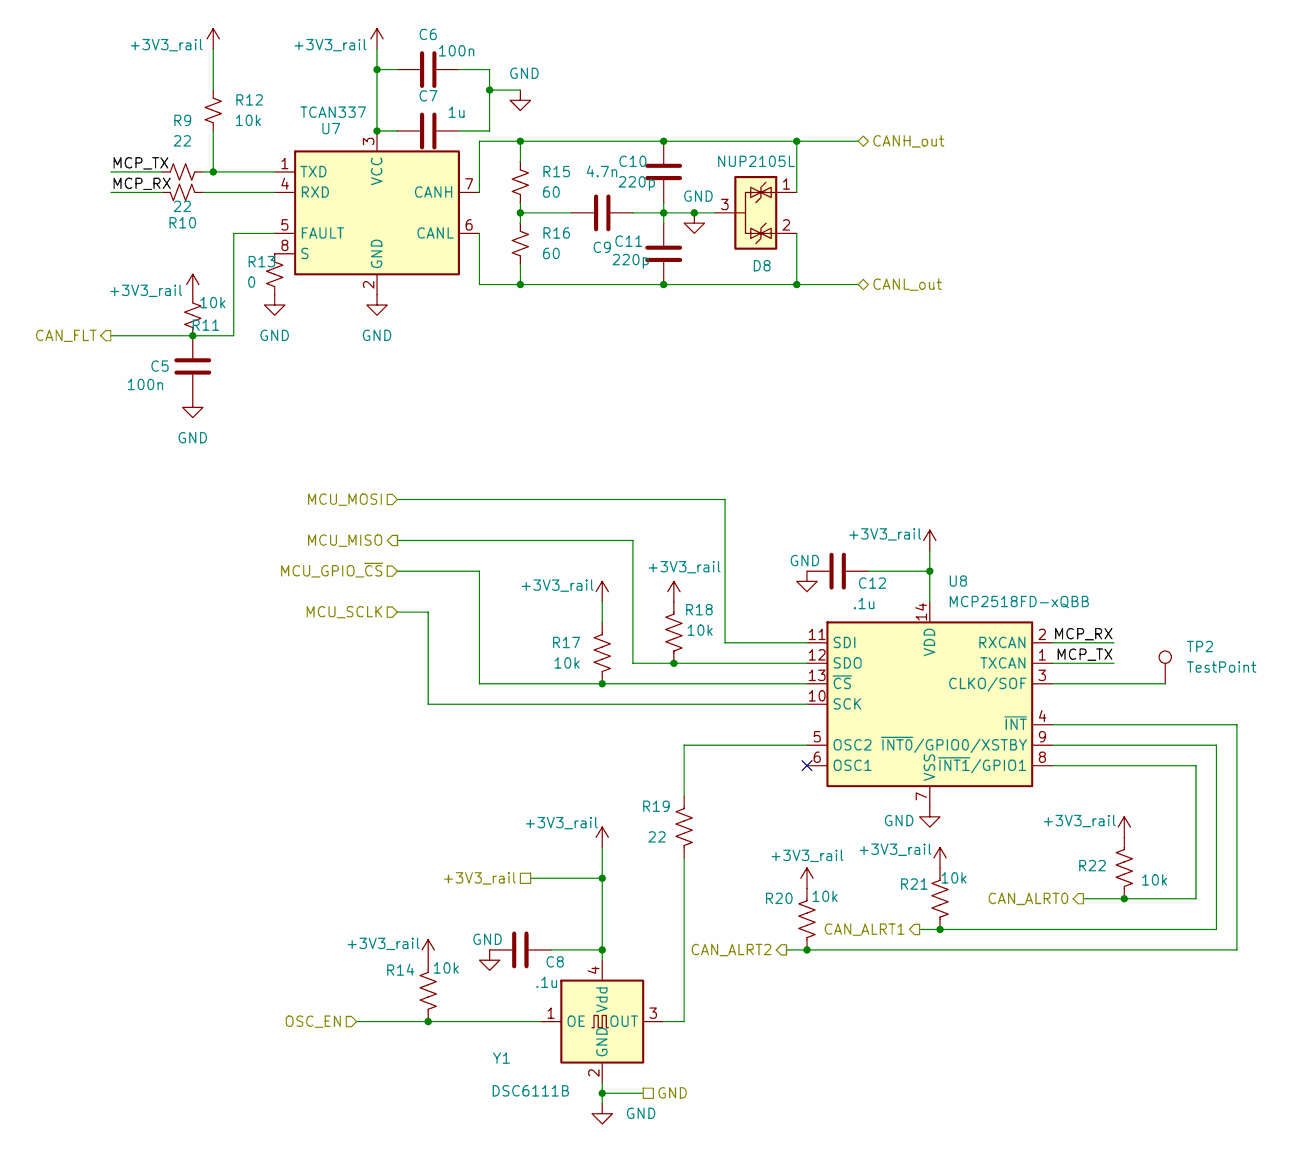
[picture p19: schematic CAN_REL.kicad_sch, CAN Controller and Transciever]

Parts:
C5, C6: 100n; C_0603_1608Metric_Pad1.08x0.95mm_HandSolder
C7: 1u; C_0603_1608Metric_Pad1.08x0.95mm_HandSolder
C8, C12: .1u; C_0603_1608Metric_Pad1.08x0.95mm_HandSolder
C9: 4.7n; C_0603_1608Metric_Pad1.08x0.95mm_HandSolder
C10, C11: 220p; C_0603_1608Metric_Pad1.08x0.95mm_HandSolder
D8: NUP2105L; SOT-23
R9, R10, R19: 22; R_0603_1608Metric_Pad0.98x0.95mm_HandSolder
R11, R12, R14, R17, R18, R20, R21, R22: 10k; R_0603_1608Metric_Pad0.98x0.95mm_HandSolder
R13: 0; R_0603_1608Metric_Pad0.98x0.95mm_HandSolder
R15, R16: 60; R_0603_1608Metric_Pad0.98x0.95mm_HandSolder
TP2: TestPoint; PinHeader_1x01_P1.00mm_Vertical
U7: TCAN337; SOIC-8_3.9x4.9mm_P1.27mm
U8: MCP2518FD-xQBB; SOIC-14_3.9x8.7mm_P1.27mm
Y1: DSC6111B; Oscillator_SMD_SiT_PQFN-4Pin_2.0x1.6mm

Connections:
+3V3_rail: C6.2, C7.2, C8.2, C12.2, R11.1, R12.2, R14.2, R17.2, R18.2, R20.2, R21.2, R22.2, U7.3 (VCC), U8.14 (VDD), Y1.4 (Vdd); also elsewhere on the board
/CAN Related/MCP_RX: R10.1, U8.2 (RXCAN)
/CAN Related/MCP_TX: R9.2, U8.1 (TXCAN)
/CANH_out: C10.2, D8.1 (K), R15.1, U7.7 (CANH); also elsewhere on the board
/CANL_out: C11.1, D8.2 (K), R16.2, U7.6 (CANL); also elsewhere on the board
/CAN_ALRT0: R22.1, U8.8 (~INT1/GPIO1); also elsewhere on the board
/CAN_ALRT1: R21.1, U8.9 (~INT0/GPIO0/XSTBY); also elsewhere on the board
/CAN_ALRT2: R20.1, U8.4 (~INT); also elsewhere on the board
/CAN_FLT: C5.2, R11.2, U7.5 (FAULT); also elsewhere on the board
/MCU_GPIO_~CS: R17.1, U8.13 (~CS); also elsewhere on the board
/MCU_MISO: R18.1, U8.12 (SDO); also elsewhere on the board
/MCU_MOSI: U8.11 (SDI); also elsewhere on the board
/MCU_SCLK: U8.10 (SCK); also elsewhere on the board
/OSC_EN: R14.1, Y1.1 (OE); also elsewhere on the board
unnamed: C9.1, R15.2, R16.1
unnamed: R10.2, U7.4 (RXD)
unnamed: R13.2, U7.8 (S)
unnamed: R9.1, R12.1, U7.1 (TXD)
unnamed: TP2.1, U8.3 (CLKO/SOF)
unnamed: R19.2, U8.5 (OSC2)
unnamed: R19.1, Y1.3 (OUT)

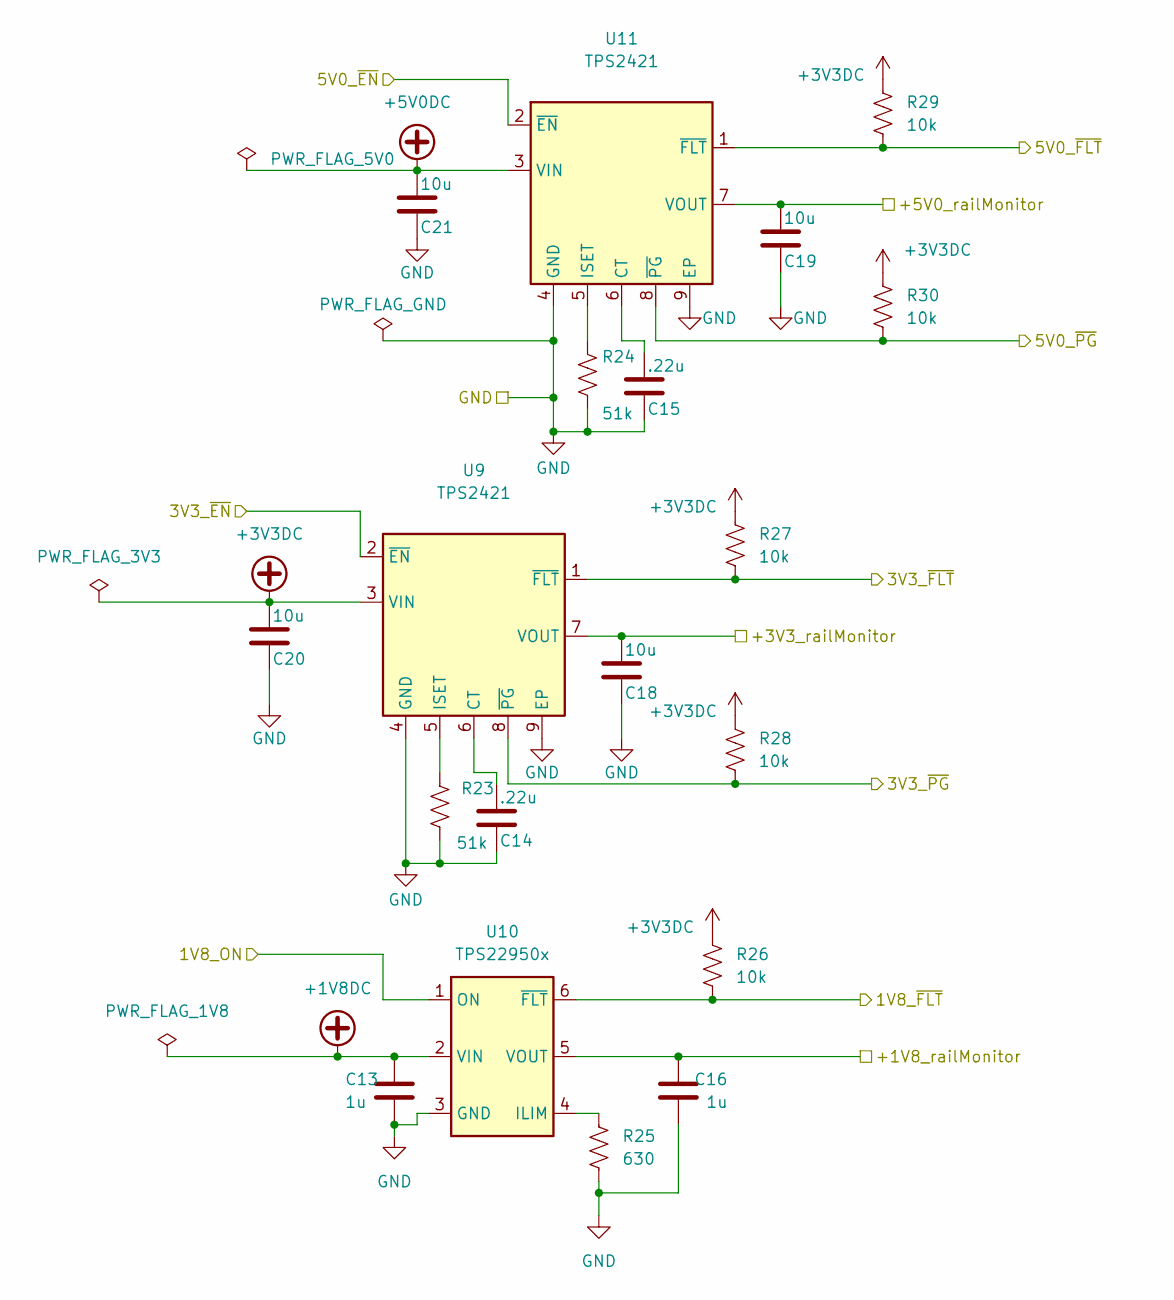
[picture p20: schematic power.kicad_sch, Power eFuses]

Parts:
C13, C16: 1u; C_0603_1608Metric_Pad1.08x0.95mm_HandSolder
C14, C15: .22u; C_0603_1608Metric_Pad1.08x0.95mm_HandSolder
C18, C19, C20, C21: 10u; C_0603_1608Metric_Pad1.08x0.95mm_HandSolder
R23, R24: 51k; R_0603_1608Metric_Pad0.98x0.95mm_HandSolder
R25: 630; R_0603_1608Metric_Pad0.98x0.95mm_HandSolder
R26, R27, R28, R29, R30: 10k; R_0603_1608Metric_Pad0.98x0.95mm_HandSolder
U9, U11: TPS2421; HSOP-8-1EP_3.9x4.9mm_P1.27mm_EP2.41x3.1mm_ThermalVias
U10: TPS22950x; SOT-23-6

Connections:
+1V8DC: C13.2, U10.2 (VIN); also elsewhere on the board
+3V3DC: C20.2, R26.2, R27.2, R28.2, R29.2, R30.2, U9.3 (VIN); also elsewhere on the board
+5V0DC: C21.2, U11.3 (VIN); also elsewhere on the board
/1V8_ON: U10.1 (ON); also elsewhere on the board
/1V8_~FLT: R26.1, U10.6 (~FLT); also elsewhere on the board
/3V3_~EN: U9.2 (~EN); also elsewhere on the board
/3V3_~FLT: R27.1, U9.1 (~FLT); also elsewhere on the board
/3V3_~PG: R28.1, U9.8 (~PG); also elsewhere on the board
/5V0_~EN: U11.2 (~EN); also elsewhere on the board
/5V0_~FLT: R29.1, U11.1 (~FLT); also elsewhere on the board
/5V0_~PG: R30.1, U11.8 (~PG); also elsewhere on the board
/+1V8_railMonitor: C16.2, U10.5 (VOUT); also elsewhere on the board
/+3V3_railMonitor: C18.2, U9.7 (VOUT); also elsewhere on the board
/+5V0_railMonitor: C19.2, U11.7 (VOUT); also elsewhere on the board
unnamed: C14.2, U9.6 (CT)
unnamed: R23.2, U9.5 (ISET)
unnamed: R25.2, U10.4 (ILIM)
unnamed: C15.2, U11.6 (CT)
unnamed: R24.2, U11.5 (ISET)

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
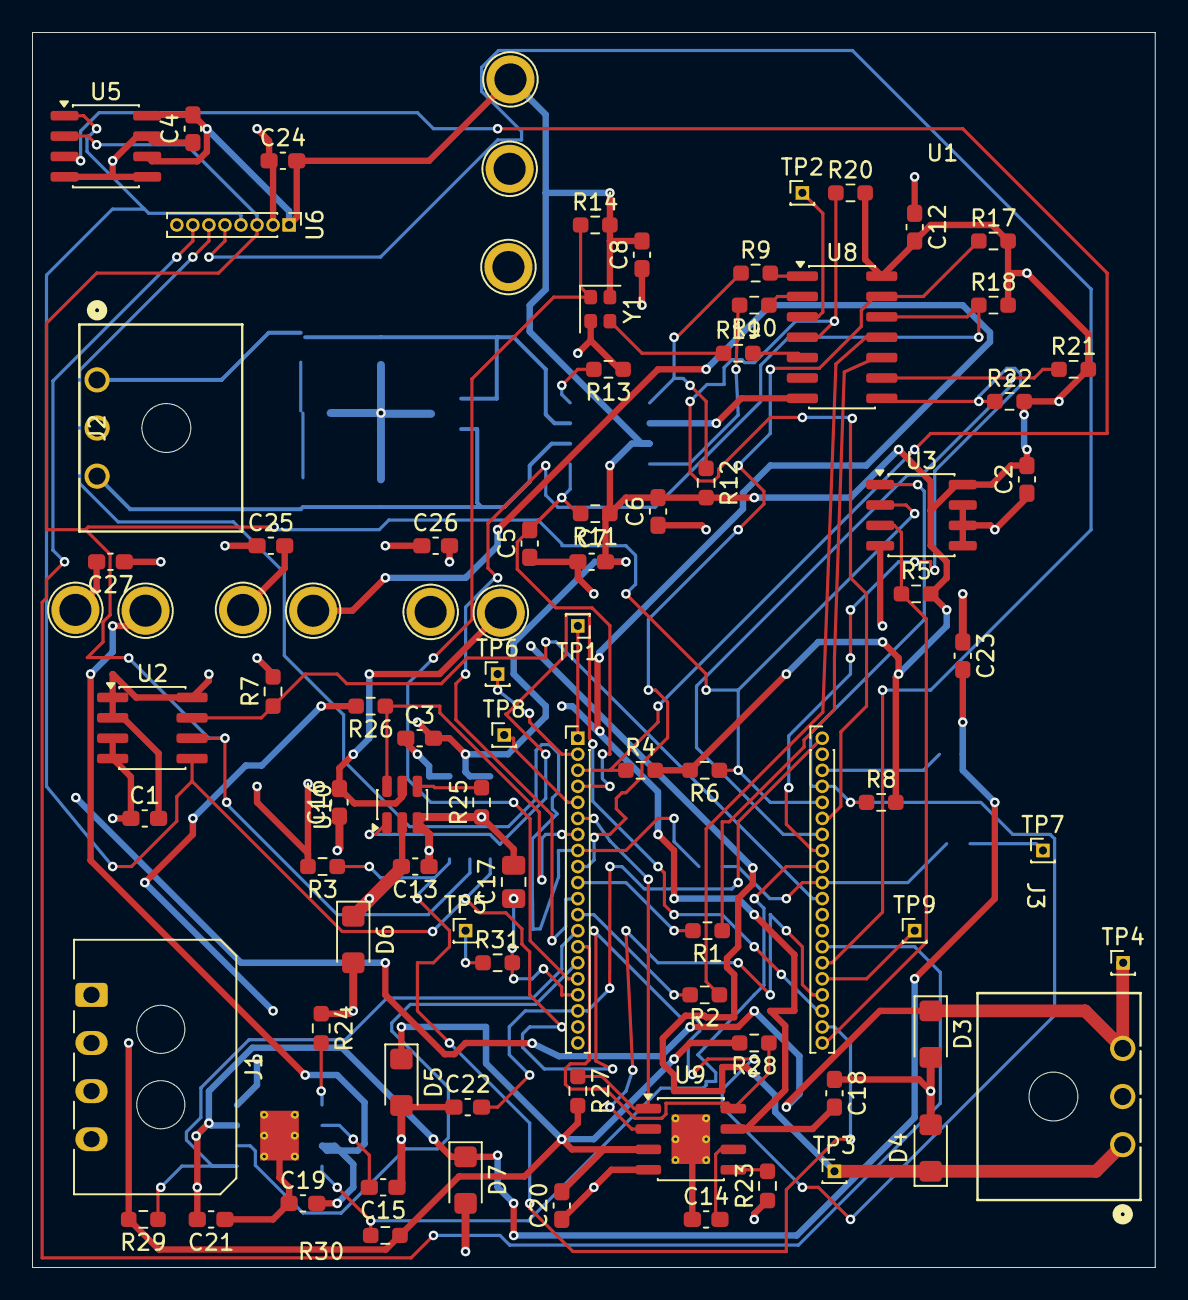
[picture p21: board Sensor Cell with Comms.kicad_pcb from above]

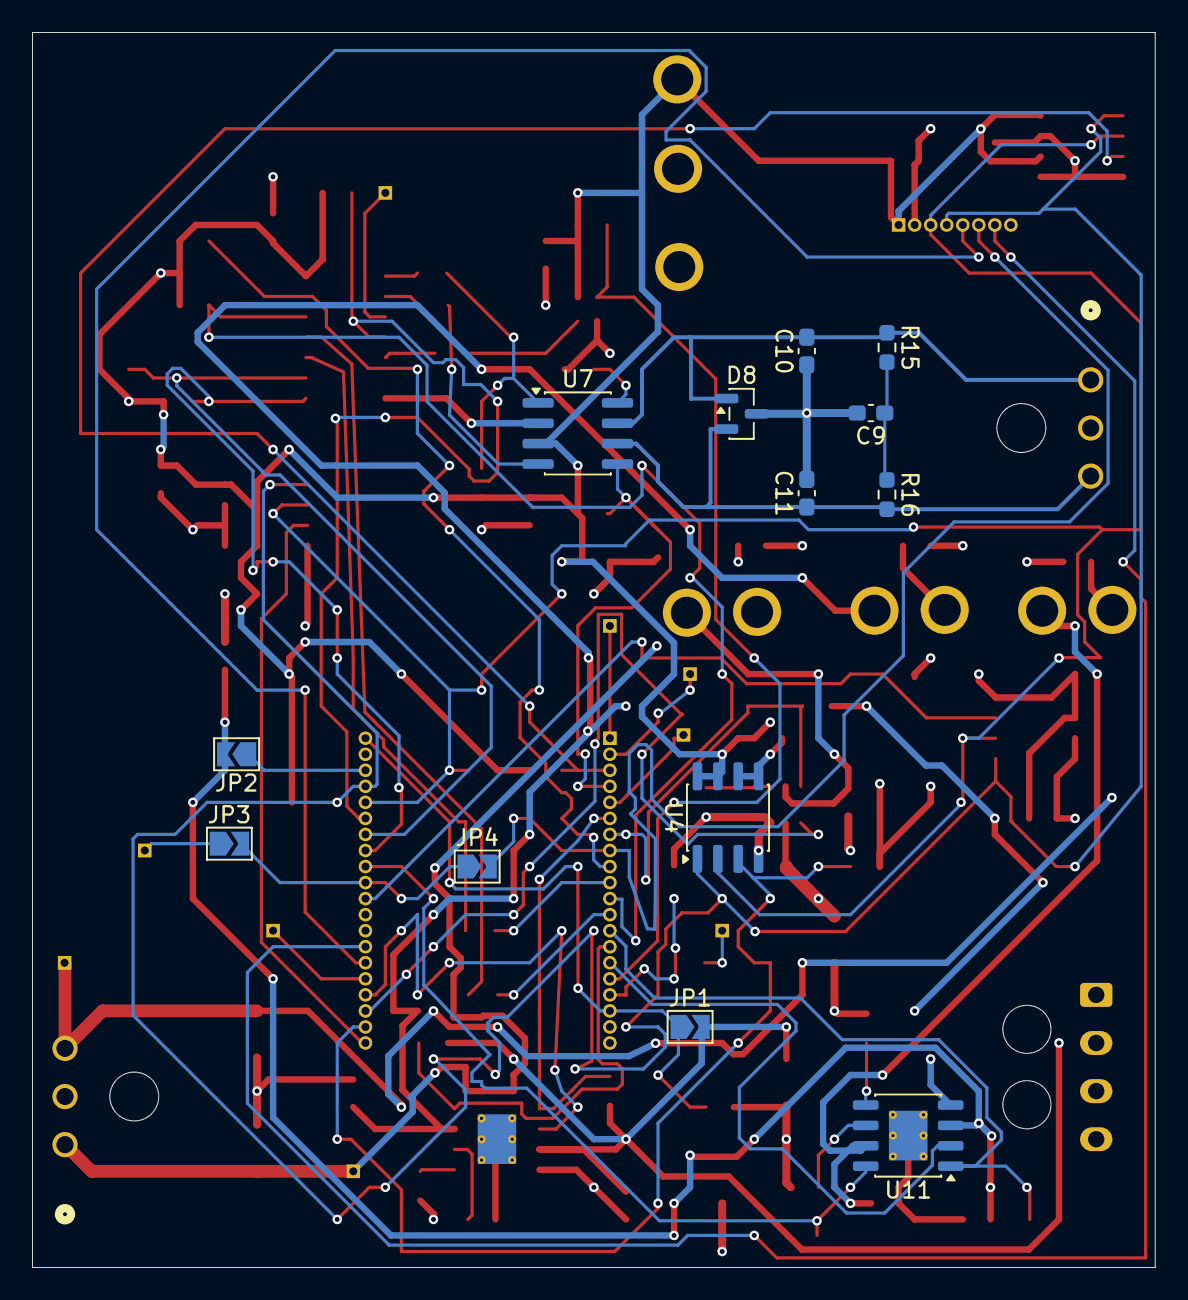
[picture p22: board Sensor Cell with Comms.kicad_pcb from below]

Board: 4 copper layers, 70.0 x 77.0 mm, 92 parts (13 on the bottom side), 64 nets.

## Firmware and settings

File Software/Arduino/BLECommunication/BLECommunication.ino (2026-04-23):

#include <BLEDevice.h>
#include <BLEUtils.h>
#include <BLEScan.h>
#include <BLEAdvertisedDevice.h>
#include <time.h>
#include <SPI.h>
#include <BLEServer.h> // (Gemini)
#include <BLE2902.h> // (Gemini)
#include <BLEHIDDevice.h> // (Gemini)
#include "HIDTypes.h"
#include "can_ctrl.h"
#include <Wire.h>

//These are our Universal Unique Identifiers (UUID).
// These are needed to ensure communication is happening on the same place.
#define SERVICE "ab2d02b4-ad53-400f-bf7e-d603a657d07d"
#define TEMP_UUID "05ac146f-aee8-4659-aba5-882c1f7e0372"
#define ALERT_UUID "58bb99f3-75cb-48cb-81e4-346cc4f0687d"
#define POWER_UUID "825ab071-bbe7-4032-82d3-558c35669279"
#define TEMP_LIMIT_UUID "8dfe11ef-25c0-47ee-a85d-f09d9e842c75"
#define POWER_RAIL_UUID "7908269a-7dfb-43f4-aa67-498191d77b8e"
#define TEMP_REQUEST_UUID "0ab3fd35-5e20-48ec-b5cb-7bf0b7260453"

//For I2C support
#define I2C_Freq 115200
#define SDA_0 18
#define SCL_0 19

// For Windows 11 Support
// Note: USED GEMINI to obtain these variables for a generic instance, as wasn't finding
// in top resources
BLEHIDDevice* hid;
BLECharacteristic* inputReport;
// Dummy variables for Windows 11 
const char* deviceManufacturer = "DOIT_ESP32";
uint16_t vid = 0x05ac; // Apple Vendor ID (often used for compatibility)
uint16_t pid = 0x820a; 
uint16_t version = 0x0210;
uint8_t batteryLevel = 100;
// Minimal HID Report Map (tells Windows this is a generic HID device)
const uint8_t _hidReportDescriptor[] = {
  0x05, 0x01,                    // USAGE_PAGE (Generic Desktop)
  0x09, 0x06,                    // USAGE (Keyboard)
  0xa1, 0x01,                    // COLLECTION (Application)
  0x85, 0x01,                    //   REPORT_ID (1)
  0x05, 0x07,                    //   USAGE_PAGE (Keyboard)
  0x19, 0xe0,                    //   USAGE_MINIMUM (Keyboard LeftControl)
  0x29, 0xe7,                    //   USAGE_MAXIMUM (Keyboard Right GUI)
  0x15, 0x00,                    //   LOGICAL_MINIMUM (0)
  0x25, 0x01,                    //   LOGICAL_MAXIMUM (1)
  0x75, 0x01,                    //   REPORT_SIZE (1)
  0x95, 0x08,                    //   REPORT_COUNT (8)
  0x81, 0x02,                    //   INPUT (Data,Var,Abs)
  0xc0                           // END_COLLECTION
};
// Below is the orginial approach that was taken for HID variables, but also would
// have needing to know the generic values listed above
//#define HID_SERVICE "1812"
//#define HID_CHAR_REPORT "2a4d" // HID inputs
//#define HID_CHAR_REPORT_MAP "2a4b" // Device usage
//#define HID_CHAR_CONTROL_POINT "2a4c"
//#define HID_CHAR_HID_INFO "2a4a"
//#define BATTERY_SERVICE "180F"
//#define BATTERY_CHAR "2a19"
//#define DEVICE_INFO_SERVICE "180a"
//#define DEVICE_INFO_CHAR_MANU_NAME "2a29"
//#define DEVICE_INFO_CHAR_MODEL_NUM "2a24"
//#define DEVICE_INFO_CHAR_SYSTEM_ID "2a23"


// Notes for SPI communication
// Pins are set to default and have corresponding preset variables from Arduino
// MOSI = 23
// MISO = 19
// SCK = 18
// SS = 5

// Variable to track state of connection
bool connection = false;
//bool sync = false;


// BLE Server, Service, and Characteristic setup. 
BLEServer *BtServer;
BLEService *BtData;
BLECharacteristic *BtTemp;
BLECharacteristic *BtPower;
BLECharacteristic *BtAlert;

BLEService *BtCommand;
BLECharacteristic *BtPowerOn;
BLECharacteristic *BtTempLimit;
BLECharacteristic *BtTempRequest;


/*
// Communication variables
uint8_t temperature; // Communication value for the temp characteristic
float commandValue; // Value for the command characteristic.
static char messenger[6]; // Message buffer for temp values
static char command[6]; // Message buffer for command values
static int pastValues[10]; // Small storage in case of delay in sending out values
int counter=0; // generic counter for loops, used later
*/

//State variables of the system
float tempLimit;
float recentTemp;



TwoWire I2C_0 = TwoWire(0);

// Event handling for the BLEServer
class MyServerCallbacks : public BLEServerCallbacks
{
  // Event of a connection. It sets the connection to true, prints status.
  void onConnect(BLEServer* BtServer){
    connection = true;
  }


  // Event of a disconnection. Sets connection to false, prints status, and then restarts advertising for a new connection.
  void onDisconnect(BLEServer* BtServer){
    connection = false;
    delay(500); // (Gemini, to account for disconnection before restarting advertising)
    BLEDevice::startAdvertising();
  }
};

// Event Handling on the Characteristic for Temperature
class MyTempCallbacks: public BLECharacteristicCallbacks
{
  // Need to add event handling for when the phone reads a value from this characteristic.
  void onRead(BLECharacteristic* BtTemp){
    //update with reading from I2C    
  }

};

class MyAlertCallbacks: public BLECharacteristicCallbacks
{
  //Reading the alert values
  void onRead(){}
  //ACK for alerts
  void onWrite(){}
}

class MyPowerCallbacks: public BLECharacteristicCallbacks
{
  //Reading the power status of the local device.
  void onRead(){}
}

class MyPowerOnCallbacks: public BLECharacteristicCallbacks
{
  //this is written with example values, the actual which I don't currently know
  // 
  void onWrite(BLECharacteristic* BtPowerOn){
    String input;
    input = BtPowerOn->getValue();
    if(input.compareTo("on") == 0){
      //send message to turn power on
    }
    else if(input.compareTo("off") == 0){
      //send message to turn power rail off
    }
    else{
      //ignore, input matches no expected value
    }
  }
};


// Event handling for the TempLimit characteristic.
class MyTempLimitCallbacks: public BLECharacteristicCallbacks
{
  void onWrite(BLECharacteristic* BtTempLimit){
    String input;
    input = BtTempLimit->getValue();
    if(input.toFloat() == 0){
      tempLimit = input.toFloat();
      //Added I2C to push limit to CAN ESP
    }
  }
};

class MyTempRequestCallbacks: public BLECharacteristicCallbacks
{

  void onWrite(BLECharacteristic* BtTempRequest){
    String input;
    input = BtTempRequest->getValue();
    if(input.compareTo("sync") == 0){
      //begin sync process
      //find length of remaining data locally, then repeatedly query I2C for local values from FRAM
      //Send values over in a combined format if possible
    }
    else if(input.compareTo("now") == 0){
      //Immediate value

      //find if we have the immediate in local queue
      //then either send it or request from I2C what value to send
    }
    else{
      //Disregard any input here
    }
    
  }
}



// Setup code!
void setup() {
  I2C_0.begin(SDA_0, SCL_0, I2C_Freq);
  // Setup for testing, can remove later.
  // Starting the baud rate to 115200, necessary for BLE readings.
  Serial.begin(115200);
  // We initialize the BLE device, and then create a server on this device. Set callbacks as well.
  BLEDevice::init("MyESP32");
  BtServer = BLEDevice::createServer();
  BtServer->setCallbacks(new MyServerCallbacks);

  // HID (Majority as template from GitHub BLEKeyboard)
  hid = new BLEHIDDevice(BtServer);
  inputReport = hid->inputReport(1); // Report ID 1 (Gemini)
  hid->manufacturer()->setValue(deviceManufacturer);
  hid->pnp(0x02, vid, pid, version);
  hid->hidInfo(0x00, 0x01);
  BLESecurity* pSecurity = new BLESecurity();
  pSecurity->setAuthenticationMode(ESP_LE_AUTH_REQ_SC_MITM_BOND);
  hid->reportMap((uint8_t*)_hidReportDescriptor, sizeof(_hidReportDescriptor));
  hid->startServices();
  if (hid != 0)
    hid->setBatteryLevel(batteryLevel);

  // Creating a service to be run. This is run on the server. Refer to diagram on interface documentation for how the service is set up.
  BtData = BtServer->createService(SERVICE);
  // Setting up 2 characteristics to be a part of the BtData service. Again, refer to diagram in interface documentation for how the service is set up.
  BtTemp = BtData->createCharacteristic(TEMP_UUID, BLECharacteristic::PROPERTY_READ | BLECharacteristic::PROPERTY_NOTIFY);
  BtTemp->addDescriptor(new BLE2902()); // (Gemini)
  BtTemp->setCallbacks(new MyTempCallbacks);

  BtPower = BtData->createCharacteristic(POWER_UUID, BLECharacteristic::PROPERTY_READ | BLECharacteristic::PROPERTY_NOTIFY);
  BtPower->addDescriptor(new BLE2902()); // (Gemini)
  BtPower->setCallbacks(new MyPowerCallbacks);

  BtAlert = BtData->createCharacteristic(ALERT_UUID, BLECharacteristic::PROPERTY_READ | BLECharacteristic::PROPERTY_NOTIFY);
  BtAlert->addDescriptor(new BLE2902()); // (Gemini)
  BtAlert->setCallbacks(new MyAlertCallbacks);

  BtPowerOn = BtData->createCharacteristic(POWER_RAIL_UUID, BLECharacteristic::PROPERTY_READ | BLECharacteristic::PROPERTY_WRITE | BLECharacteristic::PROPERTY_NOTIFY);
  BtPowerOn->addDescriptor(new BLE2902()); // (Gemini)
  BtPowerOn->setCallbacks(new MyPowerOnCallbacks);

  BtTempLimit = BtData->createCharacteristic(TEMP_LIMIT_UUID, BLECharacteristic::PROPERTY_READ | BLECharacteristic::PROPERTY_WRITE | BLECharacteristic::PROPERTY_NOTIFY);
  BtTempLimit->addDescriptor(new BLE2902()); // (Gemini)
  BtTempLimit->setCallbacks(new MyTempLimitCallbacks);

  BtTempRequest = BtData->createCharacteristic(TEMP_REQUEST_UUID, BLECharacteristic::PROPERTY_READ | BLECharacteristic::PROPERTY_WRITE | BLECharacteristic::PROPERTY_NOTIFY);
  BtTempRequest->addDescriptor(new BLE2902()); // (Gemini)
  BtTempRequest->setCallbacks(new MyTempRequestCallbacks);
  // Starting the BLE stack
  BtData->start();
  // HID Service start
  hid->startServices();
  //onStarted(BtServer);
  // Setting up advertising for a device to try to connect to this.
  BLEAdvertising *BtAdvert = BLEDevice::getAdvertising();
  BtAdvert->addServiceUUID(SERVICE); //Adding the service UUID to what the ESP is advertising.
  // Need to confirm if these settings are necessary for iPhone communication. I had found that these were preferred settings, but they might be unnecessary
  BtAdvert->setScanResponse(true);
  BtAdvert->setMinPreferred(0x06);
  BtAdvert->setMinPreferred(0x12);
  //Additional HID advertising
  BtAdvert->addServiceUUID(hid->hidService()->getUUID());
  BtAdvert->setAppearance(GENERIC_HID); // Crucial: Tell Windows it's a HID device (Gemini)
  BtAdvert->setAdvertisementType(ADV_TYPE_IND); // (Gemini) Make sure don't have invisible connection
  // Device actually starts advertising.
  // And to find associated values quicker, providing labels to services, characteristics
  BLEAdvertisementData advertisementData;
  advertisementData.setName("MyESP32"); // In case if some scanners don't catch it all the time
  advertisementData.setManufacturerData("DoIt");
  advertisementData.setServiceData(BLEUUID(SERVICE), "Temperature Service");

  BLEDevice::startAdvertising();
  Serial.println("All set up. Please test.");
  //SPI setup, using default pins
  SPI.begin();
}

// General loop to constantly run.
void loop() {
  // Loop does nothing if there's no connection to anything. 
  if(connection){
    delay(1000)
  } else {
    //Serial.println("Not connected in the loop");
  }
  delay(100);
}

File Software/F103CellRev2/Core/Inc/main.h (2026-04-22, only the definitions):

#define OnboardLED_Pin GPIO_PIN_13
#define OnboardLED_GPIO_Port GPIOC
#define TEMP2_ALERT_Pin GPIO_PIN_14
#define TEMP2_ALERT_GPIO_Port GPIOC
#define TEMP2_ALERT_EXTI_IRQn EXTI15_10_IRQn
#define CAN_FLT_Pin GPIO_PIN_15
#define CAN_FLT_GPIO_Port GPIOC
#define CAN_FLT_EXTI_IRQn EXTI15_10_IRQn
#define WAKE_Pin GPIO_PIN_0
#define WAKE_GPIO_Port GPIOA
#define FLT_3V3_Pin GPIO_PIN_1
#define FLT_3V3_GPIO_Port GPIOA
#define FLT_3V3_EXTI_IRQn EXTI1_IRQn
#define FLT_1V8_Pin GPIO_PIN_2
#define FLT_1V8_GPIO_Port GPIOA
#define FLT_1V8_EXTI_IRQn EXTI2_IRQn
#define INA3221_CRIT_Pin GPIO_PIN_3
#define INA3221_CRIT_GPIO_Port GPIOA
#define INA3221_CRIT_EXTI_IRQn EXTI3_IRQn
#define SPI_CS_Pin GPIO_PIN_4
#define SPI_CS_GPIO_Port GPIOA
#define MCU_SCLK_Pin GPIO_PIN_5
#define MCU_SCLK_GPIO_Port GPIOA
#define MCU_MISO_Pin GPIO_PIN_6
#define MCU_MISO_GPIO_Port GPIOA
#define MCU_MOSI_Pin GPIO_PIN_7
#define MCU_MOSI_GPIO_Port GPIOA
#define FLT_5V0_Pin GPIO_PIN_0
#define FLT_5V0_GPIO_Port GPIOB
#define FLT_5V0_EXTI_IRQn EXTI0_IRQn
#define PG3V3_Pin GPIO_PIN_1
#define PG3V3_GPIO_Port GPIOB
#define EN5V0_Pin GPIO_PIN_10
#define EN5V0_GPIO_Port GPIOB
#define OSC_EN_Pin GPIO_PIN_11
#define OSC_EN_GPIO_Port GPIOB
#define TEMP0_ALERT_Pin GPIO_PIN_12
#define TEMP0_ALERT_GPIO_Port GPIOB
#define TEMP0_ALERT_EXTI_IRQn EXTI15_10_IRQn
#define TEMP1_ALERT_Pin GPIO_PIN_13
#define TEMP1_ALERT_GPIO_Port GPIOB
#define TEMP1_ALERT_EXTI_IRQn EXTI15_10_IRQn
#define ON1V8_Pin GPIO_PIN_14
#define ON1V8_GPIO_Port GPIOB
#define EN3V3_Pin GPIO_PIN_15
#define EN3V3_GPIO_Port GPIOB
#define FreeIO_Pin GPIO_PIN_8
#define FreeIO_GPIO_Port GPIOA
#define INA3221_VALID_Pin GPIO_PIN_9
#define INA3221_VALID_GPIO_Port GPIOA
#define INA3221_VALID_EXTI_IRQn EXTI9_5_IRQn
#define INA3221_WARN_Pin GPIO_PIN_10
#define INA3221_WARN_GPIO_Port GPIOA
#define INA3221_WARN_EXTI_IRQn EXTI15_10_IRQn
#define USB__Pin GPIO_PIN_11
#define USB__GPIO_Port GPIOA
#define USB_A12_Pin GPIO_PIN_12
#define USB_A12_GPIO_Port GPIOA
#define WP_Pin GPIO_PIN_15
#define WP_GPIO_Port GPIOA
#define SingleWireOutput_Pin GPIO_PIN_3
#define SingleWireOutput_GPIO_Port GPIOB
#define PG5V0_Pin GPIO_PIN_4
#define PG5V0_GPIO_Port GPIOB
#define PG5V0_EXTI_IRQn EXTI4_IRQn
#define CAN_ALRT0_Pin GPIO_PIN_5
#define CAN_ALRT0_GPIO_Port GPIOB
#define CAN_ALRT0_EXTI_IRQn EXTI9_5_IRQn
#define CAN_ALRT1_Pin GPIO_PIN_6
#define CAN_ALRT1_GPIO_Port GPIOB
#define CAN_ALRT1_EXTI_IRQn EXTI9_5_IRQn
#define CAN_ALRT2_Pin GPIO_PIN_7
#define CAN_ALRT2_GPIO_Port GPIOB
#define CAN_ALRT2_EXTI_IRQn EXTI9_5_IRQn
#define SCL_Pin GPIO_PIN_8
#define SCL_GPIO_Port GPIOB
#define SDA_Pin GPIO_PIN_9
#define SDA_GPIO_Port GPIOB

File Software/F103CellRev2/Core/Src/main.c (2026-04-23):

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
/* Includes ------------------------------------------------------------------*/
#include "main.h"
#include "i2c.h"
#include "iwdg.h"
#include "spi.h"
#include "usb.h"
#include "gpio.h"

/* USER CODE BEGIN Includes */
#include "power_ctrl.h"
#include "ina3221_port.h"
#include "tmp75b_port.h"
#include "fram_port.h"
#include "mcp_port.h"
#include "can_ctrl.h"
#include "fault_ctrl.h"
#include "telemetry.h"
#include "self_test.h"
/*
 *
 Hardware interrupts
       |
       v
app_callbacks.c  (HAL_GPIO_EXTI_Callback)
       |
       +---> power_fault_irq_handler()   -- sets power fault flags
       +---> tmp75b_alert_irq_handler()  -- sets temp alert flags
       +---> can_ctrl_fault_irq_handler() -- sets CAN fault flags
       |
       v
fault_ctrl_process()  <-- called every main loop iteration
       |
       +-- collects flags from all modules
       +-- polls INA3221 mask register
       +-- polls PG5V0 pin
       +-- classifies severity tier
       |
       +-- TIER 1 WARNING   --> log to FRAM + CAN status frame
       +-- TIER 2 CRITICAL  --> disable rail + ESP32 alert + log + CAN
       +-- TIER 3 EMERGENCY --> full power down + ESP32 alert + log + CAN
 */
/* USER CODE END Includes */

/* USER CODE BEGIN PD */
#define IWDG_TIMEOUT_MS     500u    /* Watchdog window — kick before this */
/* USER CODE END PD */


void SystemClock_Config(void);
/**
  * @brief  The application entry point.
  * @retval int
  */
int main(void)
{

  /* MCU Configuration--------------------------------------------------------*/

  /* Reset of all peripherals, Initializes the Flash interface and the Systick. */
  HAL_Init();

  /* Configure the system clock */
  SystemClock_Config();

  /* Initialize all configured peripherals */
  MX_GPIO_Init();
  MX_I2C1_Init();
  MX_SPI1_Init();
  MX_USB_PCD_Init();
  MX_IWDG_Init();
  /* USER CODE BEGIN 2 */

  power_result_t pwr_result = power_sequence_up();
  /* If rails failed, assert ESP32 alert immediately — process() won't run yet */
  if (pwr_result != POWER_OK)
  {
      FAULT_ALERT_ASSERT();
  }

  ina3221_status_t ina_st = ina3221_init();
  /* Non-fatal at boot — process() will detect via INA3221 reads failing */
  (void)ina_st;
  tmp75b_status_t tmp_st = tmp75b_init_all();
  (void)tmp_st;
  for (int s = TMP75B_SENSOR_0; s < TMP75B_SENSOR_COUNT; s++)
  {
      tmp75b_set_limits((tmp75b_sensor_t)s, 75000, 85000);
  }

  fram_drv_init(&hi2c1);   /* compiler-confirmed name */

  self_test_result_t st_result = self_test_run();
  if (!self_test_passed(st_result))
  {
      FAULT_ALERT_ASSERT();   /* alert ESP32 — self-test failure is always serious */
  }

  mcp_port_init_device_struct();

  can_ctrl_status_t can_st = can_ctrl_init();
  (void)can_st;
  /* CAN init failure doesn't halt — telemetry will silently drop until recovered */

  fault_ctrl_init();
  telemetry_init();

  /* USER CODE END 2 */

  /* Infinite loop */
  /* USER CODE BEGIN WHILE */
  while (1)
  	  {
    /* USER CODE END WHILE */

    /* USER CODE BEGIN 3 */
      	  HAL_IWDG_Refresh(&hiwdg);
      	  fault_ctrl_process();
      	  telemetry_process();
  	  }
  /* USER CODE END 3 */
}

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


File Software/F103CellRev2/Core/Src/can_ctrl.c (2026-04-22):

/* =======================================================================
 * can_ctrl.c — CAN FD logic layer (MCP2518FD via mcp_port + Mailly driver)
 *
 * Layer stack:
 *   can_ctrl   ← this file  (message framing, FIFO mgmt, fault handling)
 *   mcp_port                (SPI HAL, CS toggling, device struct init)
 *   MCP251XFD driver        (Mailly — do NOT modify)
 * ===================================================================== */
#include "can_ctrl.h"
#include "mcp_port.h"

/* -----------------------------------------------------------------------
 * Internal state
 * --------------------------------------------------------------------- */
static volatile uint8_t  s_fault_flags  = 0u;
static can_rx_callback_t s_rx_callback  = NULL;

/* -----------------------------------------------------------------------
 * Static config — MCP251XFD_Config
 *
 * Key corrections vs. original broken version:
 *   .Bandwidth      = MCP251XFD_DELAY_16BIT_TIMES   (not _1BIT_)
 *   .INTsOutMode    = MCP251XFD_PINS_OPENDRAIN_OUT  (not _OPEN_DRAIN)
 *   .TXCANOutMode   = MCP251XFD_PINS_PUSHPULL_OUT   (not _PUSH_PULL)
 *   .SysInterruptFlags used (not .Interrupts)
 *   No .ControllerMode field — removed
 * --------------------------------------------------------------------- */
static MCP251XFD_Config s_can_config = {
    .XtalFreq      = 0,
    .OscFreq       = CAN_OSC_FREQ_HZ,
    .SysclkConfig  = MCP251XFD_SYSCLK_IS_CLKIN,
    .ClkoPinConfig = MCP251XFD_CLKO_DivBy10,
    .SYSCLK_Result = NULL,

    .NominalBitrate = CAN_NOMINAL_BITRATE,
    .DataBitrate    = CAN_DATA_BITRATE,
    .BitTimeStats   = NULL,
    .Bandwidth      = MCP251XFD_DELAY_16BIT_TIMES,
    .ControlFlags   = MCP251XFD_CAN_UNLIMITED_RETRANS_ATTEMPTS
                    | MCP251XFD_CANFD_BITRATE_SWITCHING_ENABLE
                    | MCP251XFD_CANFD_USE_ISO_CRC,

    /* INT0 → CAN_ALRT1 (TX done/err), INT1 → CAN_ALRT2 (RX not empty) */
    .GPIO0PinMode  = MCP251XFD_PIN_AS_INT0_TX,
    .GPIO1PinMode  = MCP251XFD_PIN_AS_INT1_RX,
    .INTsOutMode   = MCP251XFD_PINS_OPENDRAIN_OUT,
    .TXCANOutMode  = MCP251XFD_PINS_PUSHPULL_OUT,

    .SysInterruptFlags = MCP251XFD_INT_BUS_ERROR_EVENT
                       | MCP251XFD_INT_RX_INVALID_MESSAGE_EVENT,
};

/* -----------------------------------------------------------------------
 * Static FIFO list
 *
 * Key corrections:
 *   .Direction  = MCP251XFD_TRANSMIT_FIFO / MCP251XFD_RECEIVE_FIFO
 *                 (not MCP251XFD_TX_FIFO / _RX_FIFO)
 *   .InterruptFlags used (not .InterruptEnable)
 *   RX .Priority = PRIORITY30 (field present but ignored for RX FIFOs)
 * --------------------------------------------------------------------- */
static MCP251XFD_FIFO s_fifo_list[2] = {
    {
        /* TXQ — transmit queue */
        .Name           = CAN_TX_FIFO,
        .Size           = MCP251XFD_FIFO_8_MESSAGE_DEEP,
        .Payload        = MCP251XFD_PAYLOAD_64BYTE,
        .Direction      = MCP251XFD_TRANSMIT_FIFO,
        .Attempts       = MCP251XFD_THREE_ATTEMPTS,
        .Priority       = MCP251XFD_MESSAGE_TX_PRIORITY16,
        .ControlFlags   = MCP251XFD_FIFO_NO_CONTROL_FLAGS,
        .InterruptFlags = MCP251XFD_FIFO_TX_ATTEMPTS_EXHAUSTED_INT,
        .RAMInfos       = NULL,
    },
    {
        /* FIFO2 — receive */
        .Name           = CAN_RX_FIFO,
        .Size           = MCP251XFD_FIFO_8_MESSAGE_DEEP,
        .Payload        = MCP251XFD_PAYLOAD_64BYTE,
        .Direction      = MCP251XFD_RECEIVE_FIFO,
        .Attempts       = MCP251XFD_THREE_ATTEMPTS,
        .Priority       = MCP251XFD_MESSAGE_TX_PRIORITY30,
        .ControlFlags   = MCP251XFD_FIFO_NO_CONTROL_FLAGS,
        .InterruptFlags = MCP251XFD_FIFO_RECEIVE_FIFO_NOT_EMPTY_INT,
        .RAMInfos       = NULL,
    },
};

/* -----------------------------------------------------------------------
 * Static filter — accept all standard IDs into FIFO2.
 * Tighten AcceptanceMask once node ID scheme is finalised.
 *
 * Key correction: .PointTo (not .FIFO) for filter→FIFO mapping.
 * --------------------------------------------------------------------- */
static MCP251XFD_Filter s_filter_list[1] = {
    {
        .Filter         = CAN_FILTER_0,
        .EnableFilter   = true,
        .Match          = MCP251XFD_MATCH_ONLY_SID,
        .AcceptanceID   = 0x000u,
        .AcceptanceMask = 0x000u,   /* mask=0 accepts everything */
        .PointTo        = CAN_RX_FIFO,
    },
};

/* =======================================================================
 * can_ctrl_init
 * ===================================================================== */
can_ctrl_status_t can_ctrl_init(void)
{
    eERRORRESULT res;

    /* Init_MCP251XFD — correct function name (not MCP251XFD_Init) */
    res = Init_MCP251XFD(&mcp251xfd_dev, &s_can_config);
    if (res != ERR_OK)
    {
        return CAN_CTRL_ERR_INIT;
    }

    /* Configure FIFOs */
    res = MCP251XFD_ConfigureFIFOList(&mcp251xfd_dev, s_fifo_list, 2u);
    if (res != ERR_OK)
    {
        return CAN_CTRL_ERR_INIT;
    }

    /* Configure filters */
    res = MCP251XFD_ConfigureFilterList(&mcp251xfd_dev,
                                        MCP251XFD_D_NET_FILTER_DISABLE,
                                        s_filter_list, 1u);
    if (res != ERR_OK)
    {
        return CAN_CTRL_ERR_INIT;
    }

    /* Enter Normal CAN FD mode */
    res = MCP251XFD_RequestOperationMode(&mcp251xfd_dev,
                                         MCP251XFD_NORMAL_CANFD_MODE,
                                         true);
    if (res != ERR_OK)
    {
        return CAN_CTRL_ERR_INIT;
    }

    return CAN_CTRL_OK;
}

/* =======================================================================
 * can_ctrl_transmit
 * ===================================================================== */
can_ctrl_status_t can_ctrl_transmit(const can_telemetry_t *data)
{
    if (data == NULL)
    {
        return CAN_CTRL_ERR_TX;
    }

    MCP251XFD_CANMessage msg = {
        .MessageID    = CAN_MSGID_TELEMETRY,
        .ControlFlags = MCP251XFD_CANFD_FRAME
                      | MCP251XFD_SWITCH_BITRATE
                      | MCP251XFD_NO_FIFO,        /* NO_RTR → NO_FIFO in this driver ver */
        .DLC          = MCP251XFD_DLC_20BYTE,
        .PayloadData  = (uint8_t *)data,
    };

    eERRORRESULT res = MCP251XFD_TransmitMessageToFIFO(&mcp251xfd_dev,
                                                        &msg,
                                                        CAN_TX_FIFO,
                                                        true);
    if (res == ERR__BUFFER_FULL)   /* ERR__TXFIFO_FULL → ERR__BUFFER_FULL */
    {
        return CAN_CTRL_ERR_TX;
    }
    if (res != ERR_OK)
    {
        return CAN_CTRL_ERR_TX;
    }

    return CAN_CTRL_OK;
}
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

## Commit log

2026-01-02 Create README.md
    Describing current drafted layout
2026-02-24 Create battery_pms_charger
2026-02-27 Driver imported, along with headers for I/O
2026-03-01 Add KiCad hardware project; normalize LF; ignore lock files
    [Sensor Cell with Comms.kicad_pcb, Sensor Cell with Comms.kicad_sch]
2026-03-02 KiCad hardware files
2026-03-02 TCAN337 Wiring diagram redone to include the componenent sizing for the pcb stage
    [Sensor Cell with Comms.kicad_sch]
2026-03-02 PCB IO Table for STM32
2026-03-02 need to finish TPS22950x model and wiring but good now for the rest. After wiring diag is done finish actual wiring and move onto PCB process
    [Sensor Cell with Comms.kicad_sch]
2026-03-03 TPS22950x model done and included
    [Sensor Cell with Comms.kicad_sch]
2026-03-03 Adding random feature, and skeleton of SPI and sync process
2026-03-03 hardware re-work mostly done, need to finish EXTq mapping. So far INTs are grouped into 4 banks, PB2,3,4 are reserved, so map those to something else if needed. CAN FLTS is on bank3, Power FLTS is ba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
    [Sensor Cell with Comms.kicad_sch]
2026-03-04 mostly done with schematic, need to add FRAM chip, ESP<-->STM, and finish the MCP2518 crystal selection and supporting caps for crystal, wants 40 MHz
    [Sensor Cell with Comms.kicad_sch]
2026-03-04 added files for the oscillator for the MCP, finished wiring connections in general, need to finish the footprint for the osc and then make PCB using the provided autogenerated nets from KICAD
    [Sensor Cell with Comms.kicad_sch]
2026-03-07 Footprint for Osc done, osc wired to MCP and STM wired to Osc. I need to make the pcb now, and then determine what type of connector to use. Things to keep in mind when choosing; Needs to either supp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
    [Sensor Cell with Comms.kicad_sch]
2026-03-07 forgot pdf of schematic
2026-03-07 Added a reset value to the IOS app
    [BLECommunication.ino]
2026-03-17 Added breakout header pins to footprints for STM and MCP2518, need to make MCU master table, EXTI# summary table, and device connection table
    [CAN_REL.kicad_sch, Sensor Cell with Comms.kicad_pcb, Sensor Cell with Comms.kicad_sch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]
2026-03-17 Finished schematic, added all footprints, finishing ERC now to move onto the PCB planner to have Kicad do most of the heavy lifting
    [CAN_REL.kicad_sch, Sensor Cell with Comms.kicad_sch, SensorBlock.kicad_sch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]
2026-03-18 Bulk done to resolve ERC errors, went from 70 to 25. Need to resolve the remaining errors before generation of the PCB. Decided on Hirose Electric Connectors since theyre low profile and locking
    [CAN_REL.kicad_sch, Sensor Cell with Comms.kicad_sch, SensorBlock.kicad_sch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]
2026-03-19 Schematic done, and ERC passes successfully. Move onto PCB now that this is completed
    [Sensor Cell with Comms.kicad_sch, SensorBlock.kicad_sch]
2026-03-20 Delete Software/Arduino/BLECommunication/BLECommunicationWindows.ino
    Needs two additional lines to fully send and read commands/responses between browser and ESP32
2026-03-20 Updated for actual connection functionality
    To connect to the ESP32 over browser, needed to add two descriptors in order for mutual recognition
2026-03-20 First revision of PCB nearly done, Need to finish up 1v8 planes then wire components together
    [CAN_REL.kicad_sch, Sensor Cell with Comms.kicad_pcb, Sensor Cell with Comms.kicad_sch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]
2026-03-21 PCB finished, need final approval from Maxted, changed connector to Molex minifit3
    [Sensor Cell with Comms-B_Cu.gbr, Sensor Cell with Comms-B_Mask.gbr, Sensor Cell with Comms-B_Paste.gbr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]
2026-03-21 Demo circuit for CAN functionality
    [Sensor Cell with Comms.kicad_pcb, Test Circuit.kicad_pcb, Test Circuit.kicad_sch]
2026-03-28 Rev2 PCB finished, need to document and catalog for Iowa Innovation challenge this thursday
    [CAN_REL.kicad_sch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]
2026-04-08 Found a GUI driven code tool, lets me configure every pin via a GUI and now we just need to write the logical steps of what signals do what. Need to Re-add the MCP2518 open source driver since I dele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
    [CAN_REL.kicad_sch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]
2026-04-11 STM32 core firmware complete - builds clean (0 errors, 0 warnings)
    Flash usage: 31KB/32KB at -O0. Switch to -Os for release to recover headroom.
    TODO:
    - Bench: run I2C scan to confirm TMP75B U4/U5 addresses (placeholders 0x49, 0x4B)
    - Bench: update shunt resistor values in ina3221_port.h
    - Define CAN message ID scheme and tighten RX filter
    - Implement TPS2421 latch-off recovery policy
    - ESP32 firmware (separate sess)
    [Cell_F103.ioc, app_callbacks.c, can_ctrl.c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]
2026-04-22 Had to move all files to new project setup due to misconfig, Add application layer modules: power_ctrl, fault_ctrl, fram_port, ina3221_port, tmp75b_port, can_ctrl, mcp_port, telemetry, self_test, app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
    [F103CellRev2.ioc, app_callbacks.c, can_ctrl.c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]
2026-04-23 had to add build paths, 0 errors, 0 warnings, clean foundation to build on
    [main.c]
2026-04-23 BLE ESP32 skeleton, will later modify to match I2C messages. copied windows compatibility changes into BLECommunication.ino
2026-04-29 Finished sim layer for collin. Made edits to BLEconnect.swift to correctly parse incoming frames from CAN. xCode compile is saying Could not cast value of type '__NSCFNumber' to 'NSString', could be 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
    [Sensor Cell with Comms.kicad_pcb]
2026-04-30 One note: GPIO 34 and 35 are input-only on ESP32, no internal pull-up/pull-down. Woorks for INT0/INT1 since they're interrupt inputs, but the MCP2518FD's open-drain outputs will need external pull-up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
    [can_ctrl.c, can_task.c, main_canesp.c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]
2026-05-03 Changed name of ESP, small fixes to BLE
    [app_bridge.c, ble_gatt_if.c]
2026-05-03 Added timer delay for BLE notify messages
2026-05-05 Rename Sensor Cell with Comms-Sensors--IIC_BUS.svg to Sensor Cell with Comms-Sensors--IIC_BUS.svg
    Replaced || with -- for Windows pull ability
2026-05-05 Rename Sensor Cell with Comms-Sensors||IIC_BUS.svg to Sensor Cell with Comms-Sensors--IIC_BUS.svg
    Replacement of || with -- for windows ability to pull.

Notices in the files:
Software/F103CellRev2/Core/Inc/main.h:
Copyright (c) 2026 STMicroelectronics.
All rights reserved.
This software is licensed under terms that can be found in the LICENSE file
